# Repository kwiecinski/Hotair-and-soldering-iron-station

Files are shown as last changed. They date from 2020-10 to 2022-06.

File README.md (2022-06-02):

# Hotair and soldering iron station
DIY station based on STM32F103C6T8 uC that uses standard WEP/Yihua hotair flask with fan and WEP/Yihua 907A 50W soldering iron + T12 soldering iron. 

# 1. TOOLS
- PCB made in KiCAD v6.0
- 3D model made in DesignSpark Mechanical 5.0
- STM32CubeIDE v1.5 development platform

# 2. Features

# 3. Hardware

### Main PCB schematic
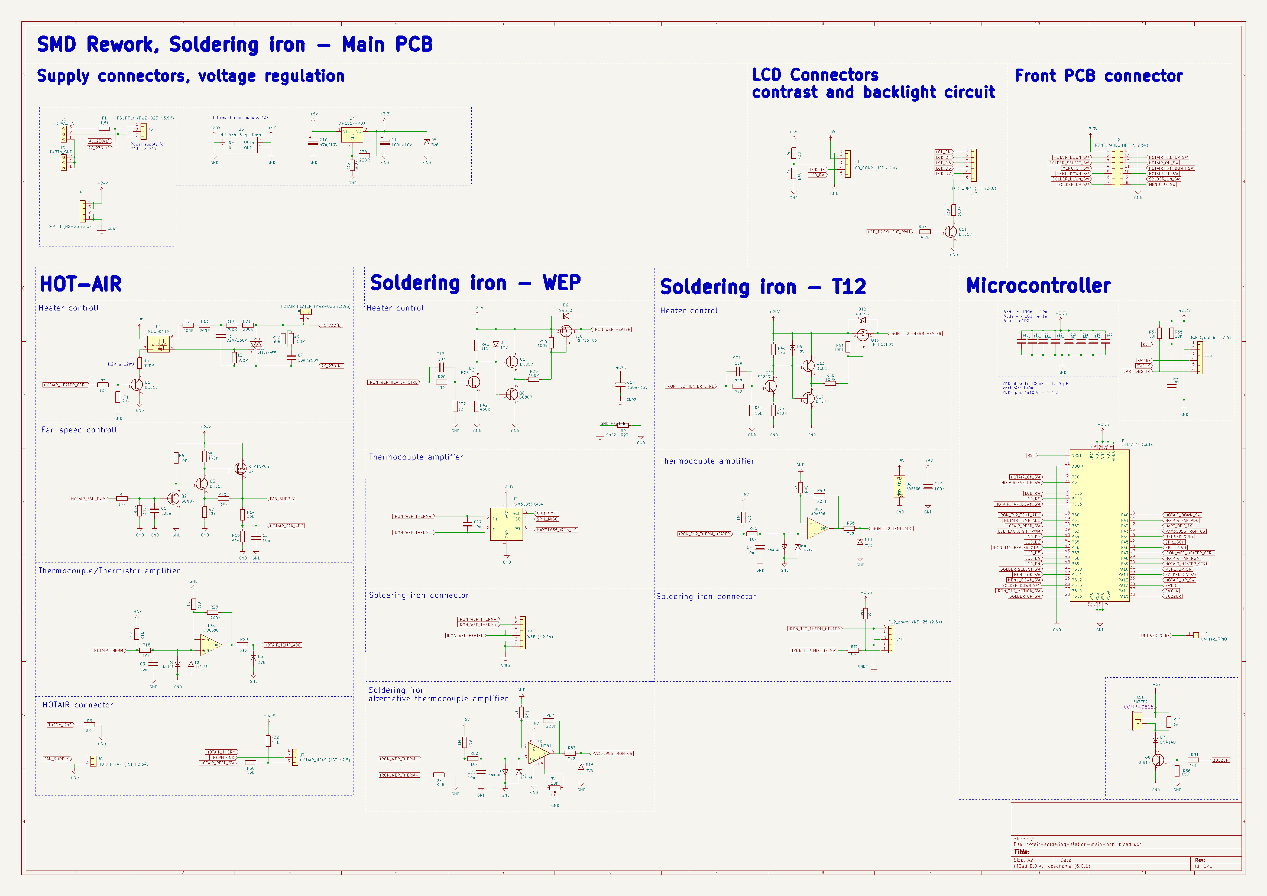
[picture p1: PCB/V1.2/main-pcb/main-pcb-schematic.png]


### Front PCB schematic
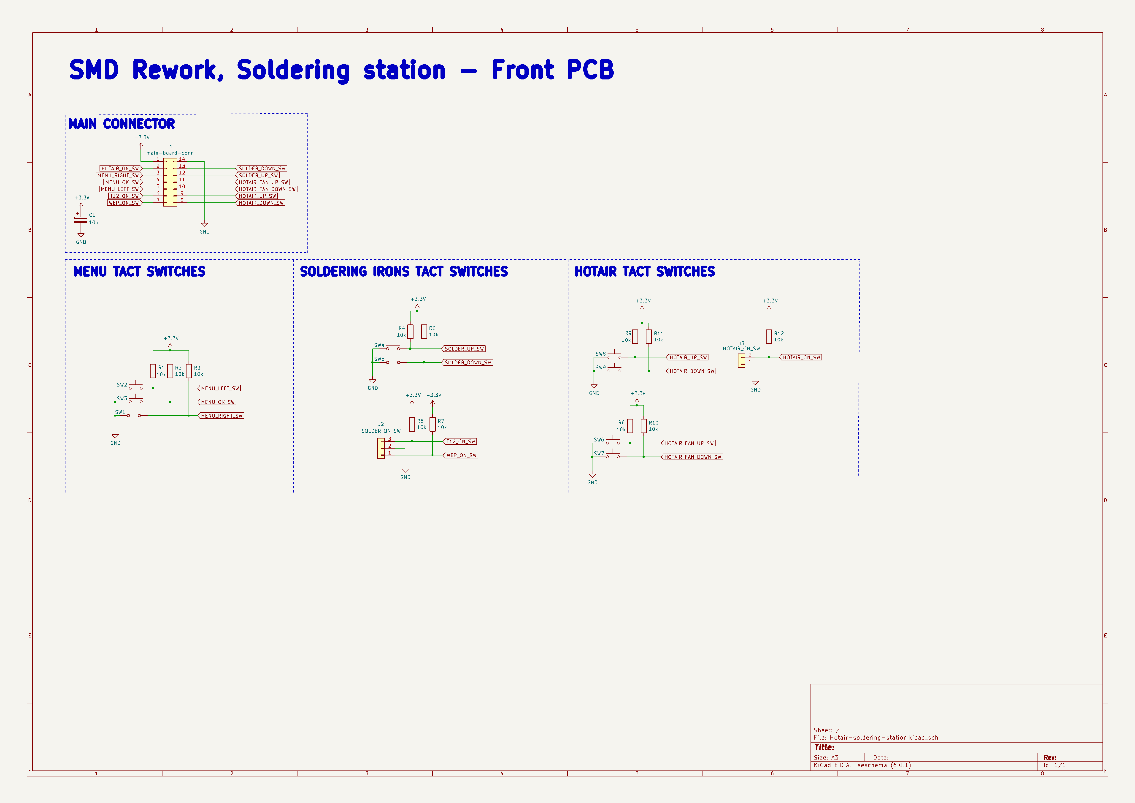
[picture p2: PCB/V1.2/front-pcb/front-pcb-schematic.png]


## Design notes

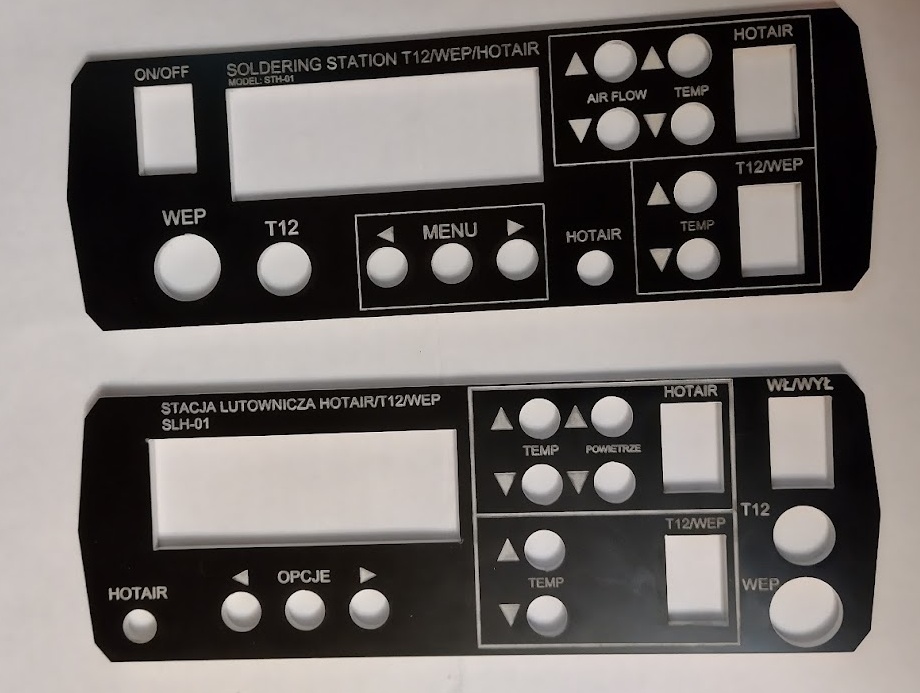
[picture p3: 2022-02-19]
docs/photos/front_panel_1.jpg

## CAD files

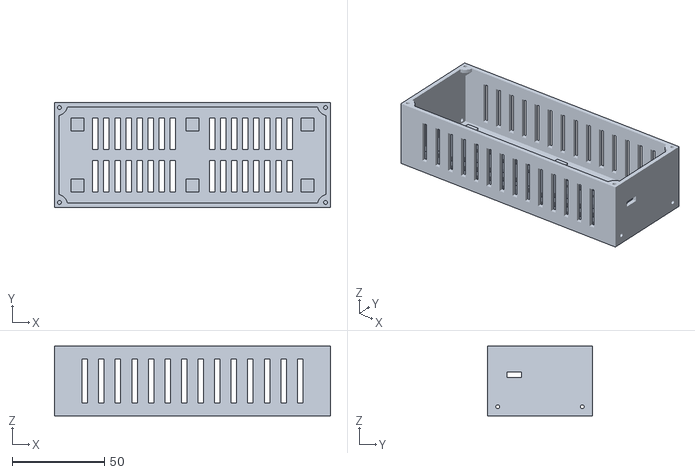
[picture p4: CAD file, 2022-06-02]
case/3D Print Models/STL/SMPS case - obudowa główna.stl
150.0 x 57.0 x 38.0

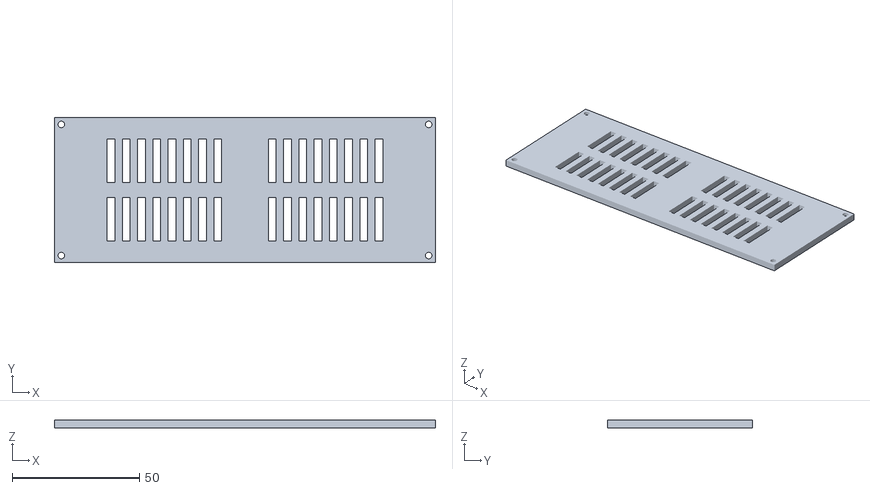
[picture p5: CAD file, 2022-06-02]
case/3D Print Models/STL/SMPS case - pokrywka.stl
150.0 x 57.0 x 3.00

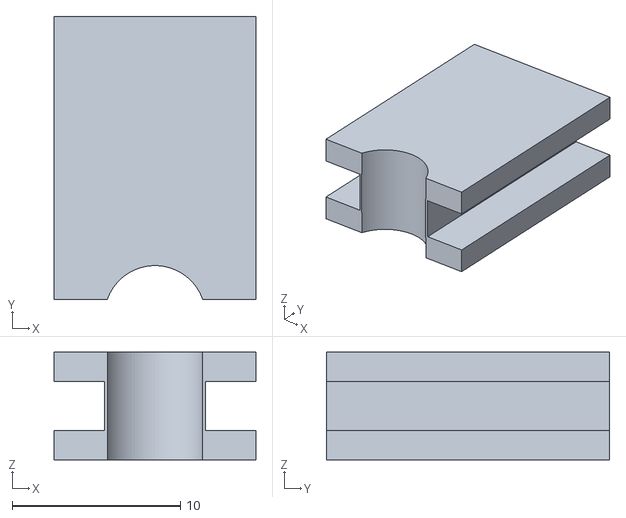
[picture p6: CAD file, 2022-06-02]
case/3D Print Models/STL/cable latch.stl
12.0 x 16.8 x 6.40

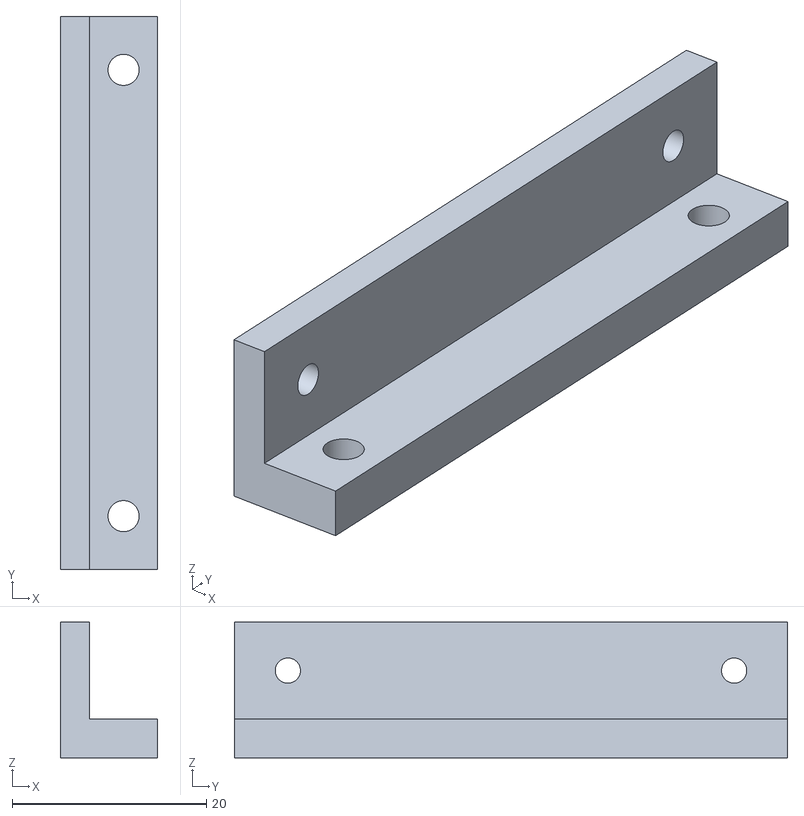
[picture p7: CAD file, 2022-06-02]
case/3D Print Models/STL/SMPS case - stopa.stl
10.0 x 57.0 x 14.0

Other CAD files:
case/Z1_Complete_documentation/Z1_2013.dwg

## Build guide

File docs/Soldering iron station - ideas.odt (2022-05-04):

1. Schematy
a. Lutownica WEP 907F

Wyjście mocy na grzałkę – stan niski brak napięcia na grzałce

Częstotliwość kluczowania >20kHz – względy akustyczne słychać kluczowanie w grzałce

Nie schodzić z wypełnieniem impulsu <10% - brak sterowania np. pushpull, nie zdąży przeładować bramki przy tej częstotliwości

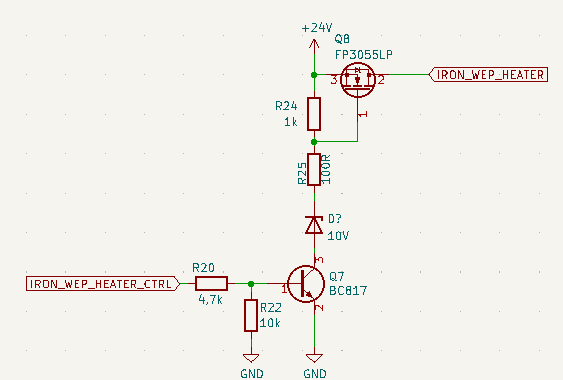
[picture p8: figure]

Pomiar temperatury:

Termopara w lutownicy – typ K – czułość 41uV/C.

Pomiar zawsze gdy grzałka nie jest zasilana! (zakłócenia)

MAX31855 nie współpracuje z grzałkami na masie, tylko izolowane !

Wykrywa rozwarcie, zwarcie itd.

Automatyczna kompensacja refrence junction.

TIM3 CH2 – konflikt z SPI1

Rozwiązania:

- Wyłączać SPI na czas działania PWM TIM3

- PA7 jako GPIO i sterować ręcznie a TIM3 przeznaczyć na timer sprzętowy ogólnego przeznaczenia

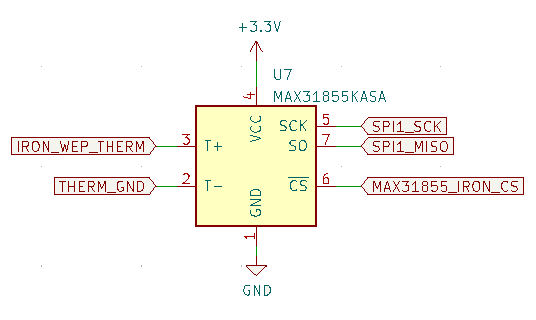
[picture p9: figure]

a. Lutownica T12

Grot zintegrowany z grzałką. Tylko trzy wyprowadzenia zasilanie i ziemia.

Grzałka jest w szeregu z termoelementem, niezbędne specjalne podejście do pomiaru.

Pomiar zawsze gdy grzałka nie jest zasilana! (inaczej nie da się)

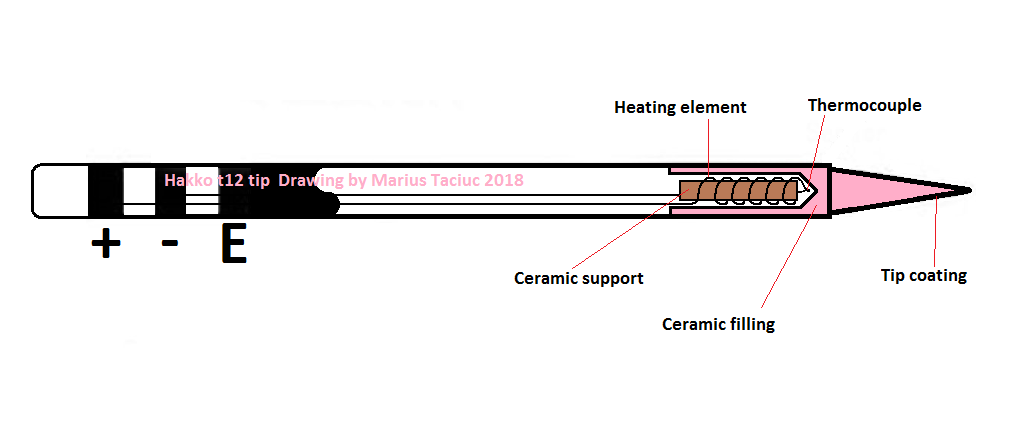
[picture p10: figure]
Hakko t12 thermocouple is not Type K! | Details | Hackaday.io

Wyjście mocy na grzałke – zasady te same co w WEP.

Wzmocnienie G=201

Termopara nie typu K, stop nieznany czułość 21uV/C

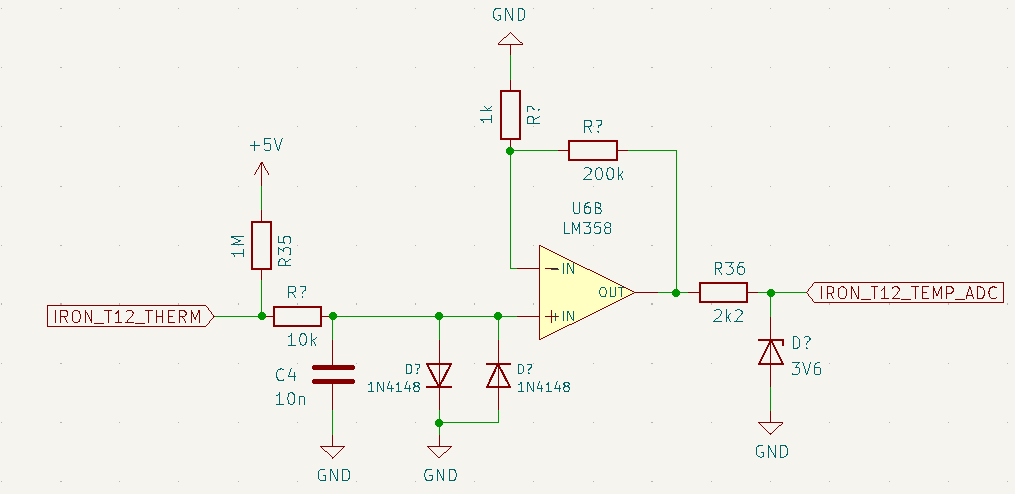
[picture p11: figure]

c) HOTAIR

Optotriak z automatycznym przejściem przez zero – sterowanie długością włączenia minimum pół okresu 50Hz czyli >10ms

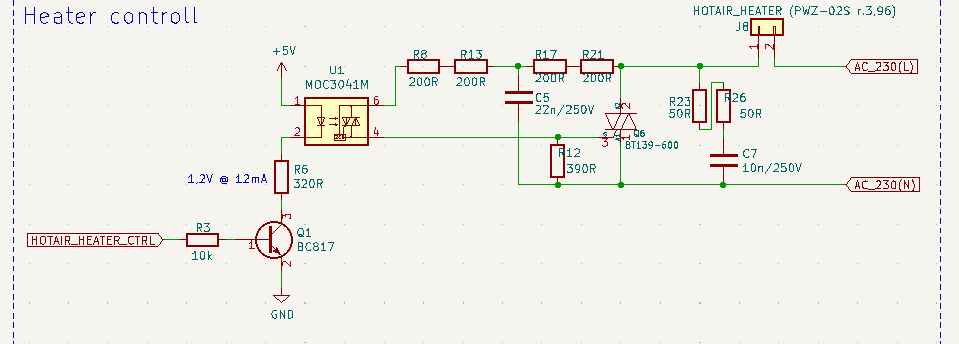
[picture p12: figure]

Pomiar temperatury:

Usunięty MAX31855.

Powody:

1. Wzmacniacz i tak musi być do pomiaru T12 – nie da rady na max bo grzałka zawsze do masy
2. Nie trzeba przerabiać kolby – w oryginalnej wspólna masa termopary z kontaktronem
3. Mamy dual omap więc szkoda żeby się jeden marnował

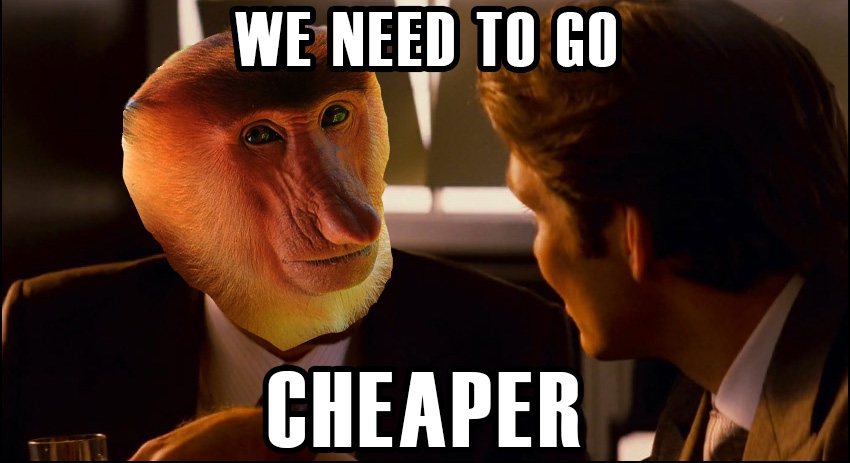
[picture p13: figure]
polak #nosaczsundajski #humorobrazkowy #heheszki - pacyfikator - Wykop.pl

Czułość 41uV/C – termopara typ K.

Schemat ten sam co w T12 z tym że wzmocnienie G=123

Pomiar zawsze gdy grzałka nie jest zasilana!

Wentylator – PWM minimum 2kHz max 10kHz

Możliwość pomiaru napięcia wentylatora

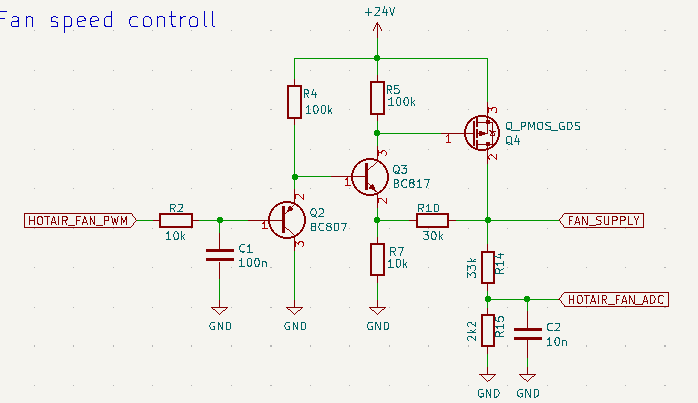
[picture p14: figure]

d) Buzzer

Rezonans przy częstotliwości 2,7kHz.

Uwaga: nie zostawiamy napięcia stałego na buzerze! Gdy nie działa zawsze na pinie stan niski!

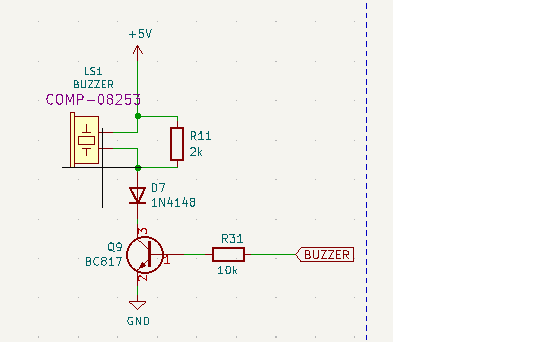
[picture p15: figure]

e) LCD

Bibloteka nie obługuje RW (jest na masie) ale jest podłączony do pinu.

PWM do regulacji podświetlenia – częstotliwość ta sama co dla buzzera bo na jednym timerze. Regulować tylko wypełeniem impulsu.

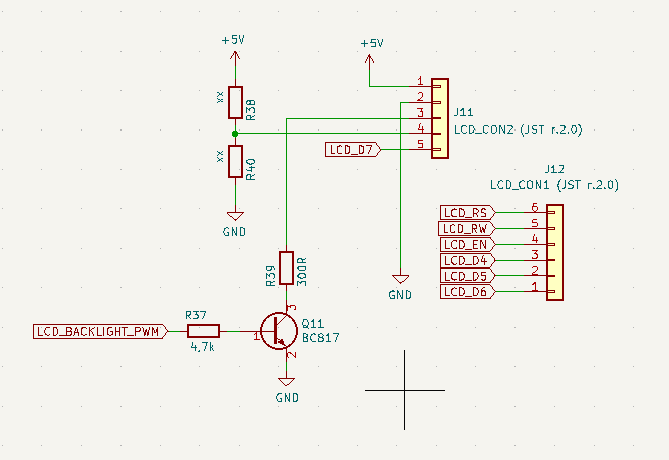
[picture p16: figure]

1. Funkcjonalność

Podstawowe:

- Ustawianie temperatury dla HOTAIR/lutownicy oraz prędkości wentylatora (nie można zejść z prędkością <40% bo się stopi hotair lub wentylator nie ruszy)

Min temp 100st max temp 450st

- Po osiągnięciu zadanej temperatury piknięcie buzzerem

- Ustawienie skoku temperatury czy wentylatora np. co 5st 10st itd.

- Standby – czas po którym po odłożeniu T12 lutownica zmniejsza temperaturę (można ustawc czas i temperaturę oraz wł/wył)

- Sleep – czas po którym po odłożeniu lutownica cała się usypia i wyłącza

- Backlight intensity – ustawienie jasności podświetlnia

- HW and SW info – werjsa oprogramowania i HW

- Buzzer on/off

- Kalibracja termopary (dla wszystkich: WEP/T12/HOTAIR)

- 3ptk dla temp. 250, 350, 430st

- powróć do domyślnych

- Wybór grotu (dla wep i T12)

- HOTAIR kontaktron, po włączeniu sprawdzamy czy jest zwarty kontaktron. Jeśli nie to trzeba odłożyć kolbę i podnieść dopiero wtedy się włącza. Po odłożeniu wentylator dalej chodzi do wychłodzenia temp. 100st

- Miganie elementu na wyświetlaczu w rytm działającego PWM

- Awarie

- Przerwanie termopary (wtedy max value na adc)

- Zwarcie do masy termopary (jeśli złączamy tranzystor a temp. Nie idzie wzrasta – błąd)

- Uszkodzenie wentylatora (ustawiony PWM a brak napięcia na adc, nie włączamy grzałki)

- Uszkodzenie tranzystora kluczującego (zwarcie – temp. Przekracza zadaną, rozwarcie – temp. Nie osiąga zadanej po określonym czasie może być zwarcie do masy termopary również)

Dodatkowe

- Praca dwóch lutownic na raz. Pomocne gdy korzystamy z różnych grotów nie trzeba przekładać.

- Uśpienie WEP – na podstawie zmian temperatury określić czy jest używana czy nie.

- Odczyt temp. uC wyświetlenie wraz z temperaturą z MAX, możliwość kompensacji refrence junction ręcznie.

- Presety temperaturowe z możliwością ustawienia

Napotkane problemy:

Resetowanie połączenia po zaprogramowaniu:

Code configurator -> SYS -> Debug -> Serial Wire

Niedziałający uart debugowy

Code configurator nie zezwala na ustawienie wyjścia jako push-pull trzeba dać rezystor.

Right-click on the syscalls.c file and select Properties. Under C/C++ Build > Settings, check Exclude resource from build.

https://shawnhymel.com/1873/how-to-use-printf-on-stm32/

Uwaga: wyłączyć prinft dla formatowania floatów.

MAX czasem daje z dupy error sprawdzać kilka razy

Ciekawostki:

Indukcyjny charakter grzałki

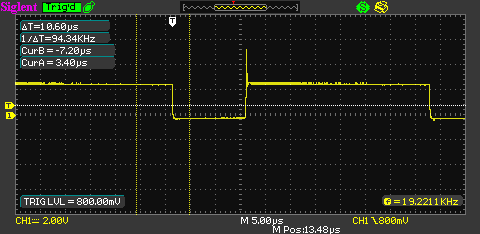
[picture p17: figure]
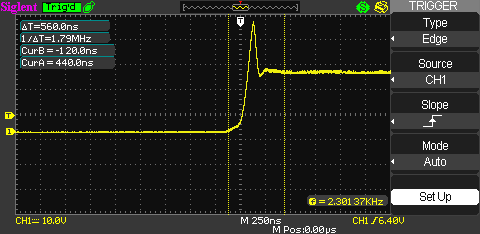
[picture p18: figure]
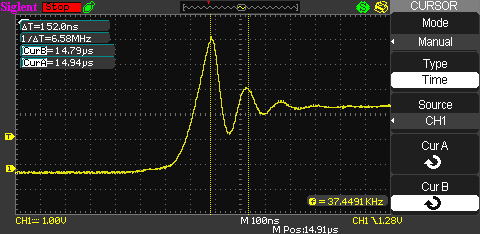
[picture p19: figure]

Triak wł/wył

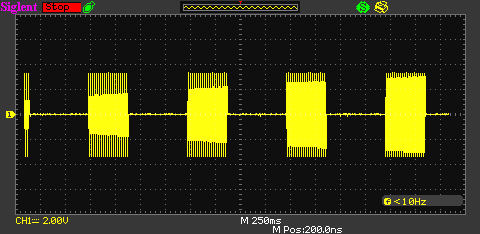
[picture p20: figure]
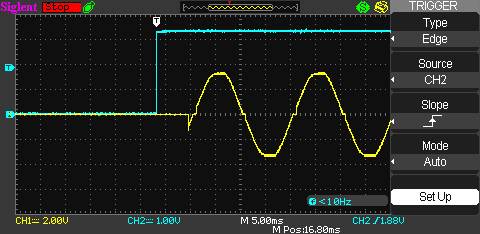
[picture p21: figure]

Analizator stanów – MAX31855

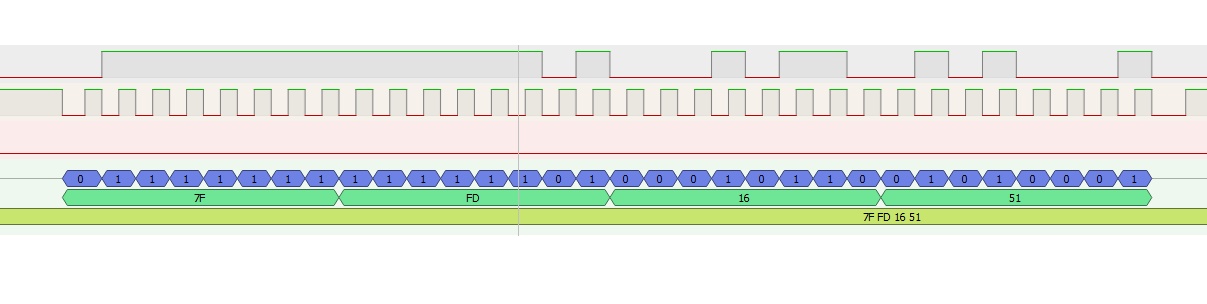
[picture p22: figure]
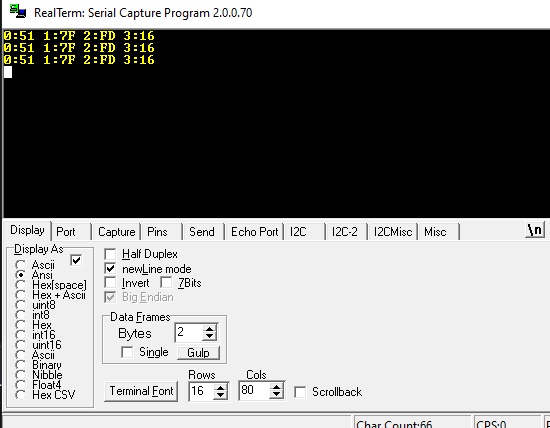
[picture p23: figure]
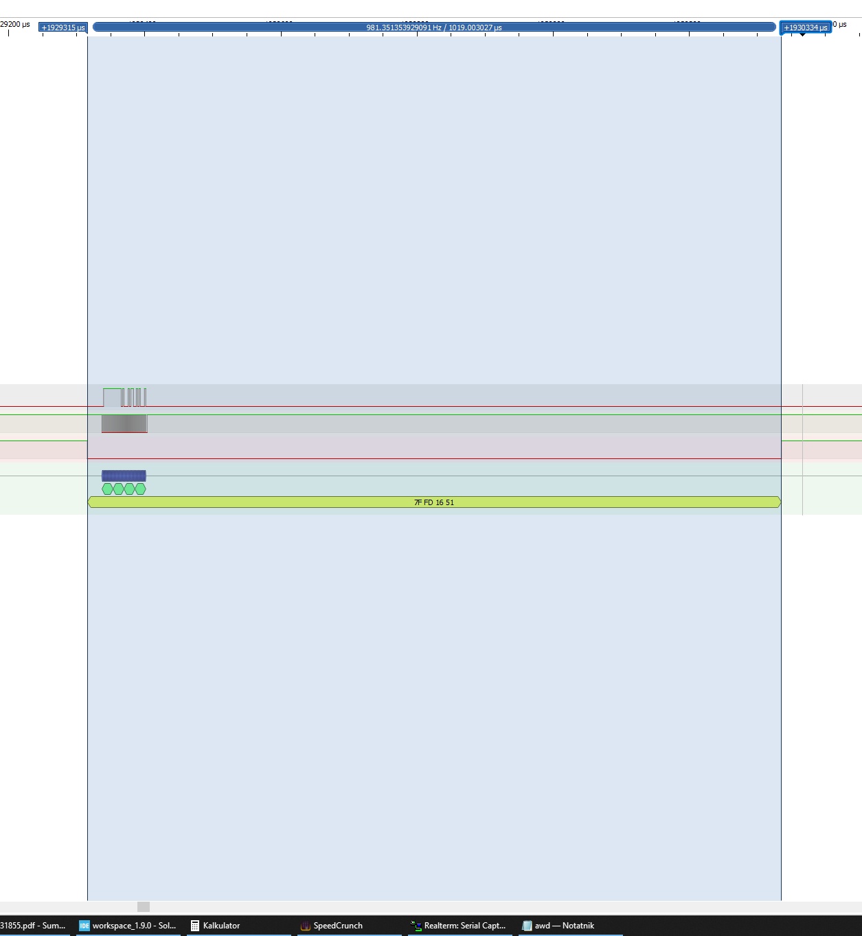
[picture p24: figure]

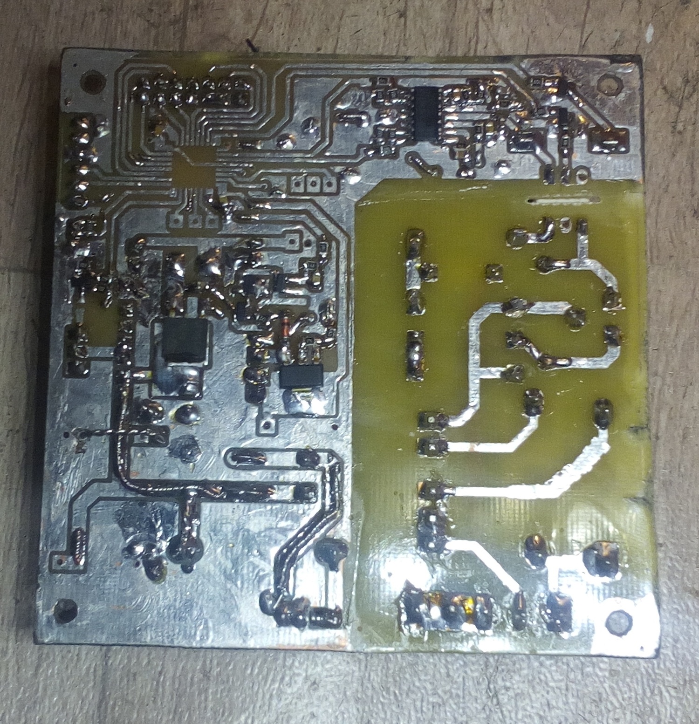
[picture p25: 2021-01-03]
docs/photos/PCB-matufacture/PCB_soldered_bottom.jpg

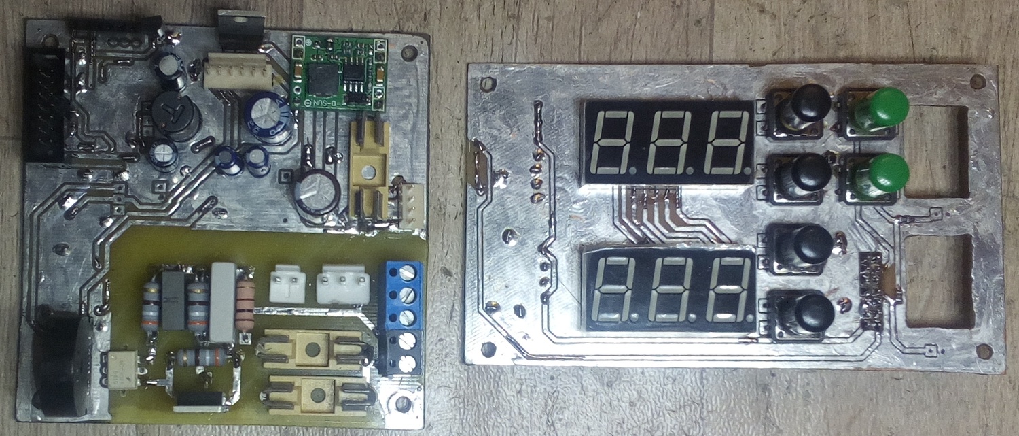
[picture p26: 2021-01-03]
docs/photos/PCB-matufacture/PCB_soldered_top.jpg

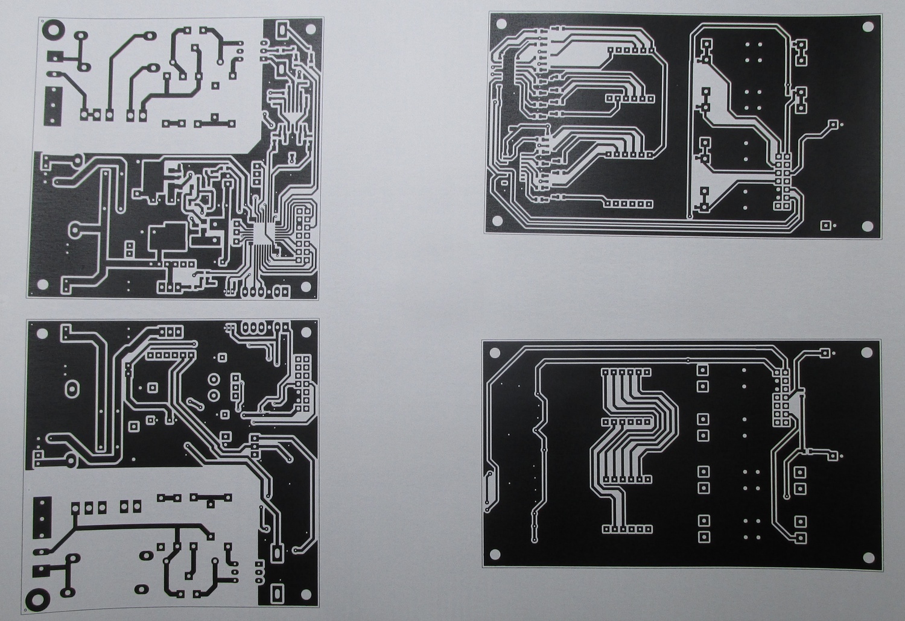
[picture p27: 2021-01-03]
docs/photos/PCB-matufacture/termotransfer_printed.JPG

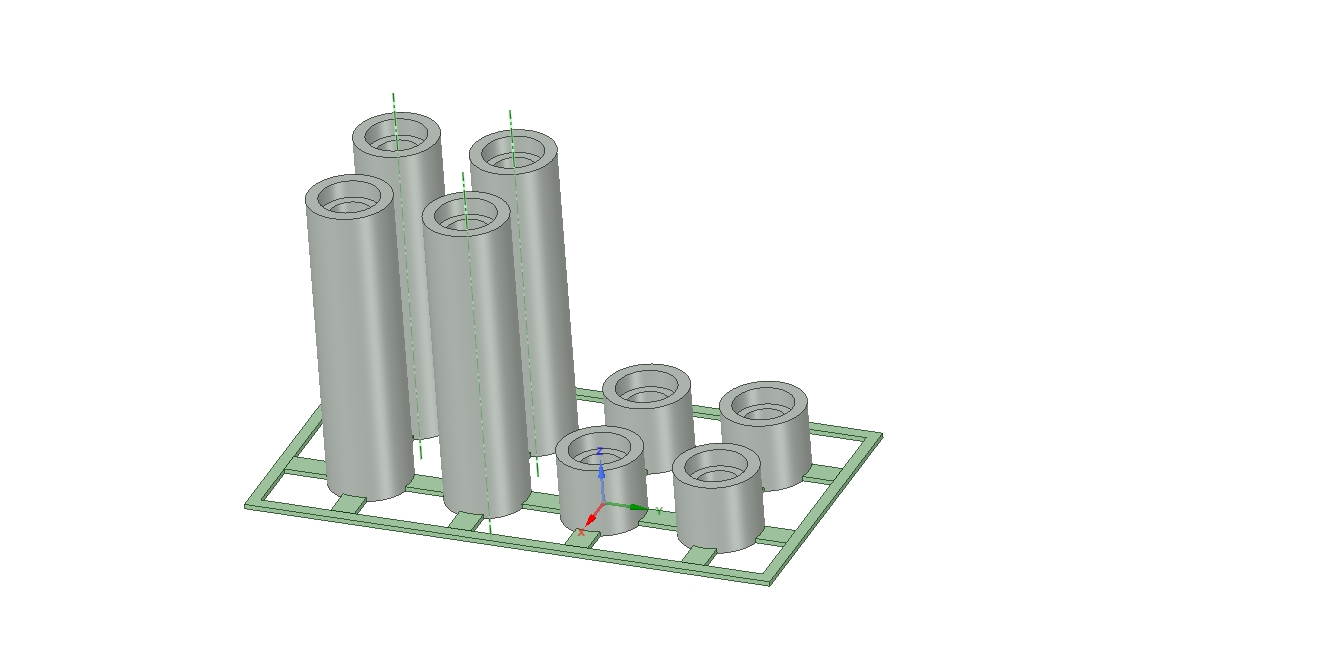
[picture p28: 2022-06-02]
case/3D Print Models/JPG/distances.jpg

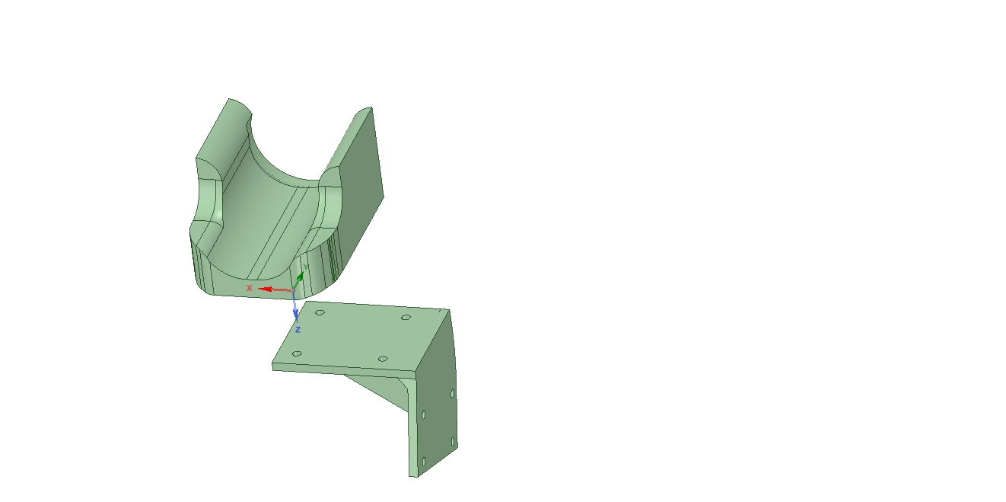
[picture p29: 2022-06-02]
case/3D Print Models/JPG/hotair holder.jpg

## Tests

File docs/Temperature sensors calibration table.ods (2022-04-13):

Zadana | Zmierzona
100 | 75
200 | 140
300 | 215
400 | 280

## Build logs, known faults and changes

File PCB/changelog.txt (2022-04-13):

V1.1
- 3V3 regulator feedback resistors values fixed
- Replace switchmode FAN converter to linear PWM
- Add MAX31855 Thermocouple interface
- Remove DC18B20
- Change MCU to STM32F103C6T6
- Change T12 6pin connector to two connector (5pin and 3pin)
- Add menu buttons
- Change display to LCD 2x16
- Add two soldering irons interface - WEP and T12 
- Change resistors in 230V heater controll circuit to smaller size
- Fix fan controll MOSFET wrong orientation

V1.2 TODO
- Add 10n capacitor and 4k7 resistor on reset
- Add 4k7 pullup resistor on debug uart
- Chane Fan regulator resistors: R7 - 2.2k, R10 - 15k, R14 - 33k, R15 - 2k2.
- Protection resistors for motion sw, reed sw

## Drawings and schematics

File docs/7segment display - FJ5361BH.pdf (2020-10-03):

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

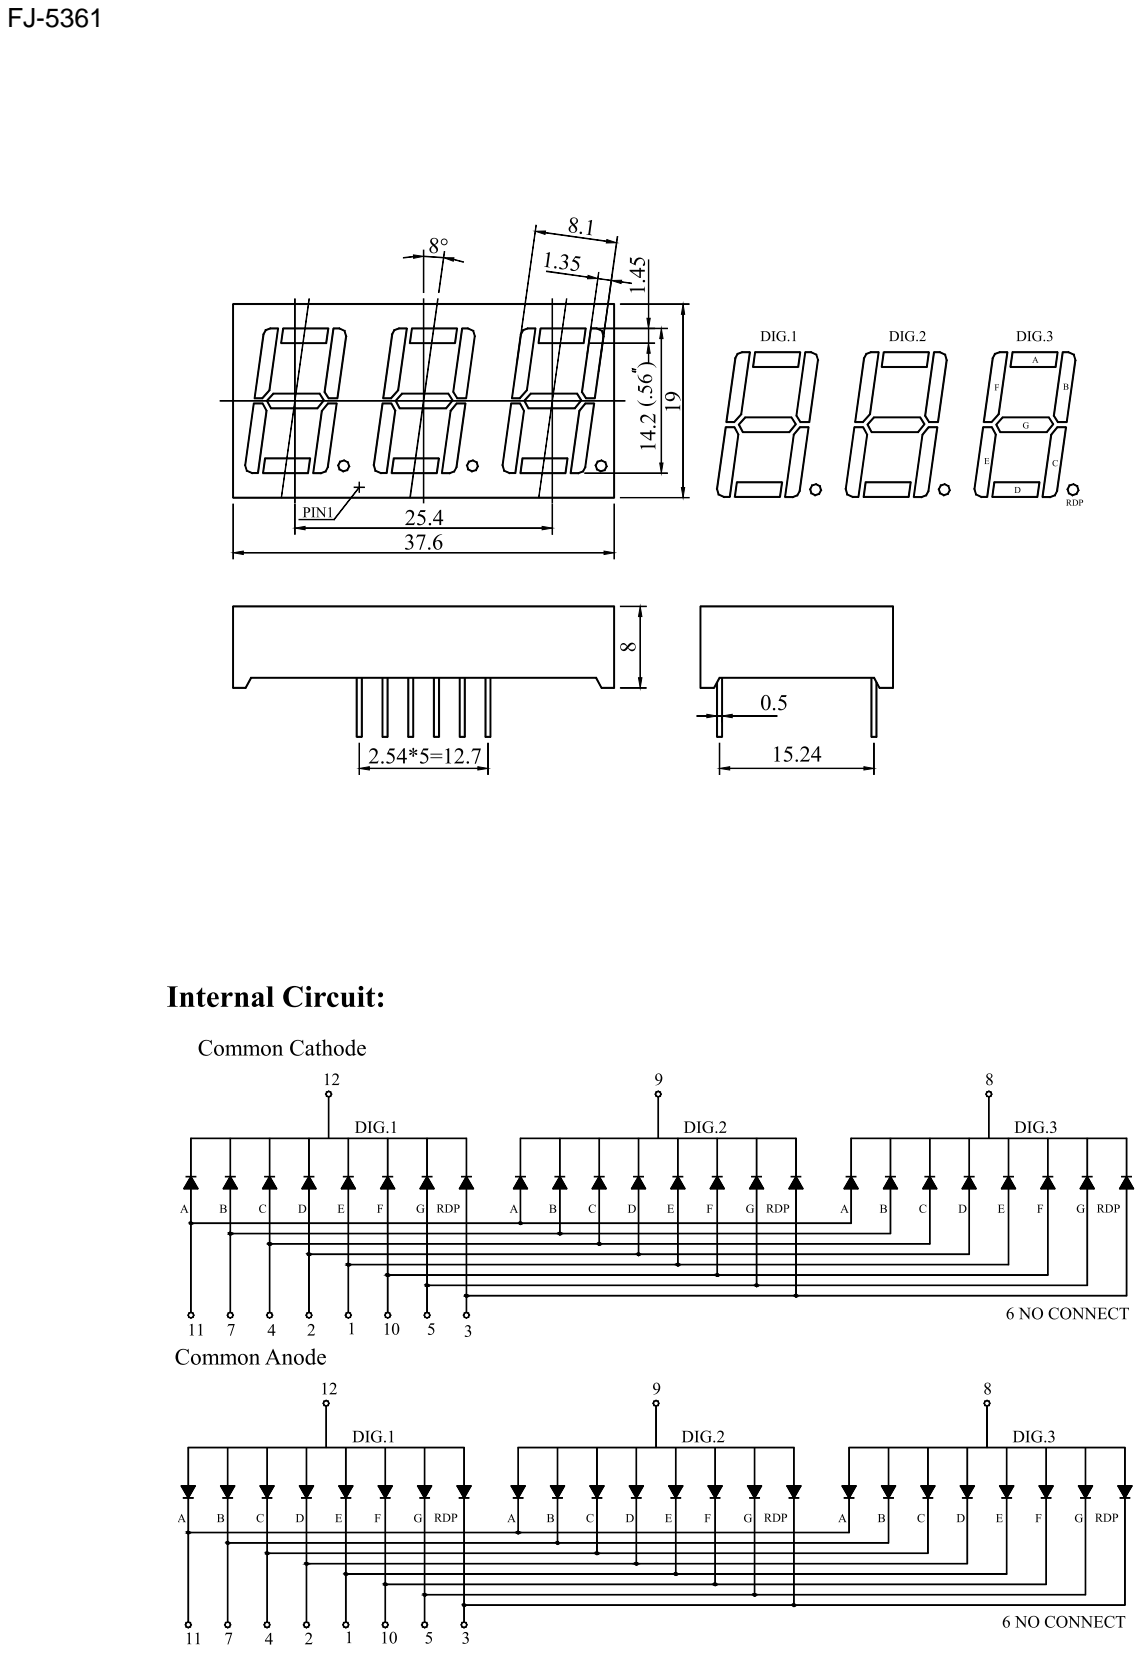
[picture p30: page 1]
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

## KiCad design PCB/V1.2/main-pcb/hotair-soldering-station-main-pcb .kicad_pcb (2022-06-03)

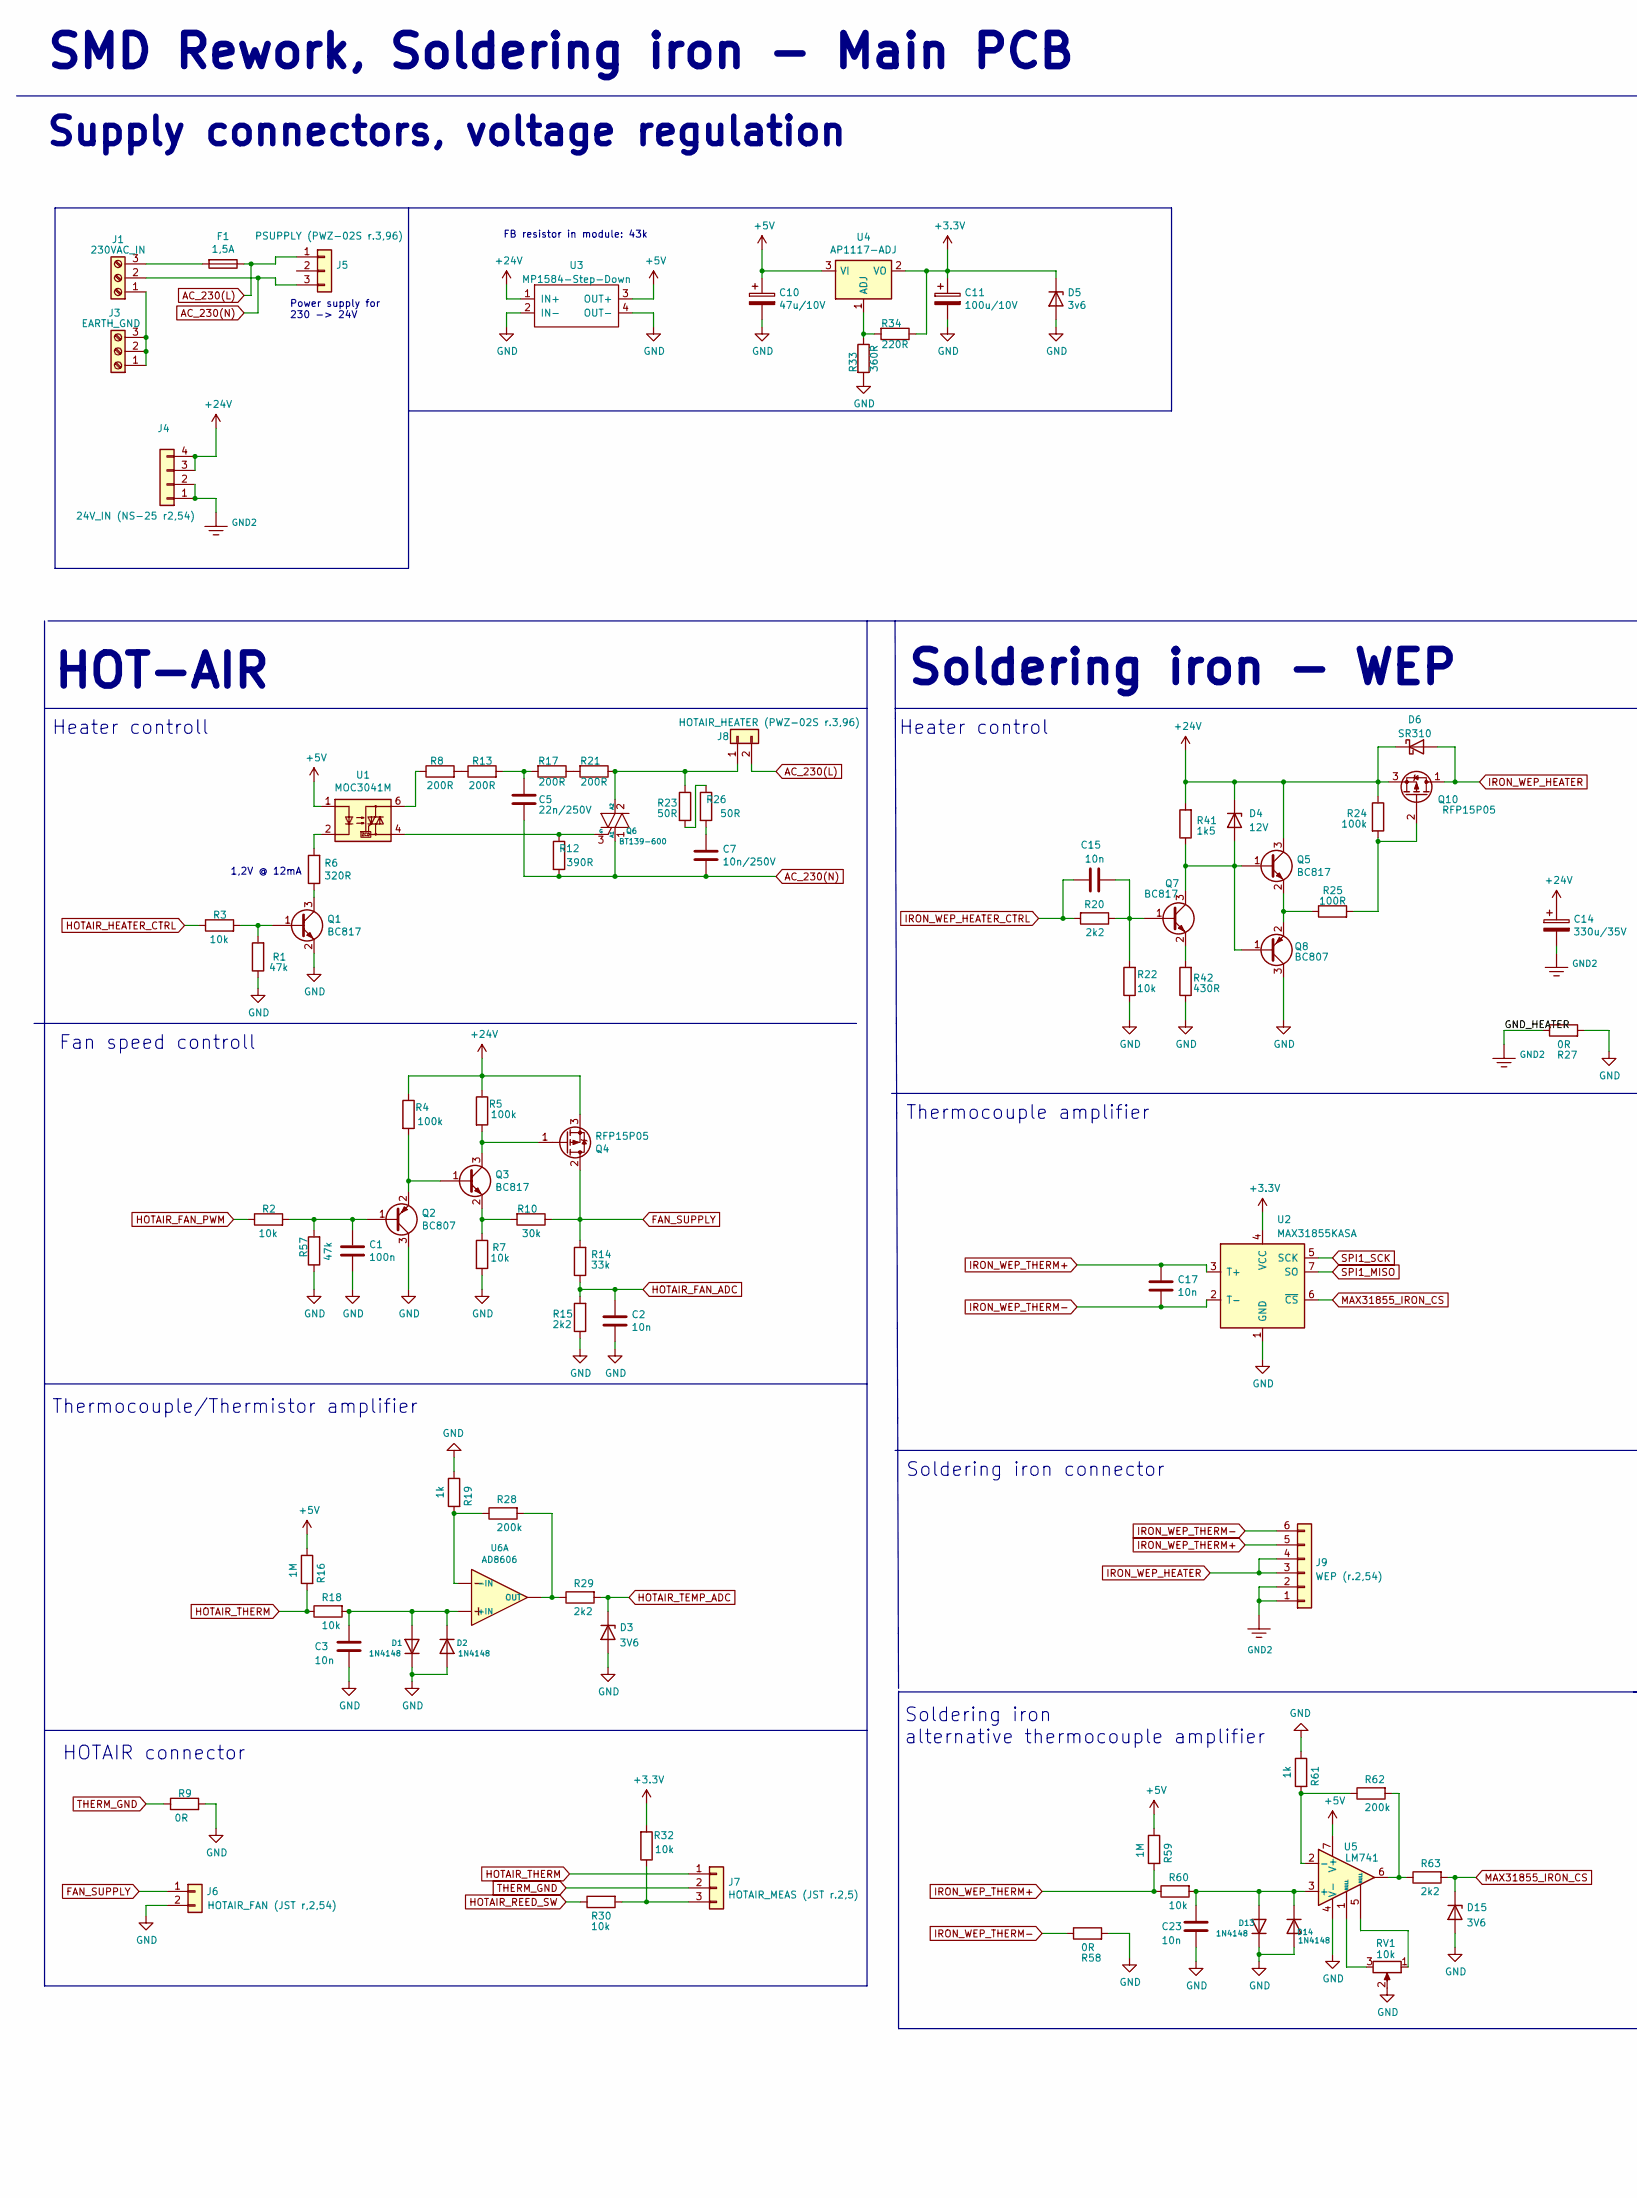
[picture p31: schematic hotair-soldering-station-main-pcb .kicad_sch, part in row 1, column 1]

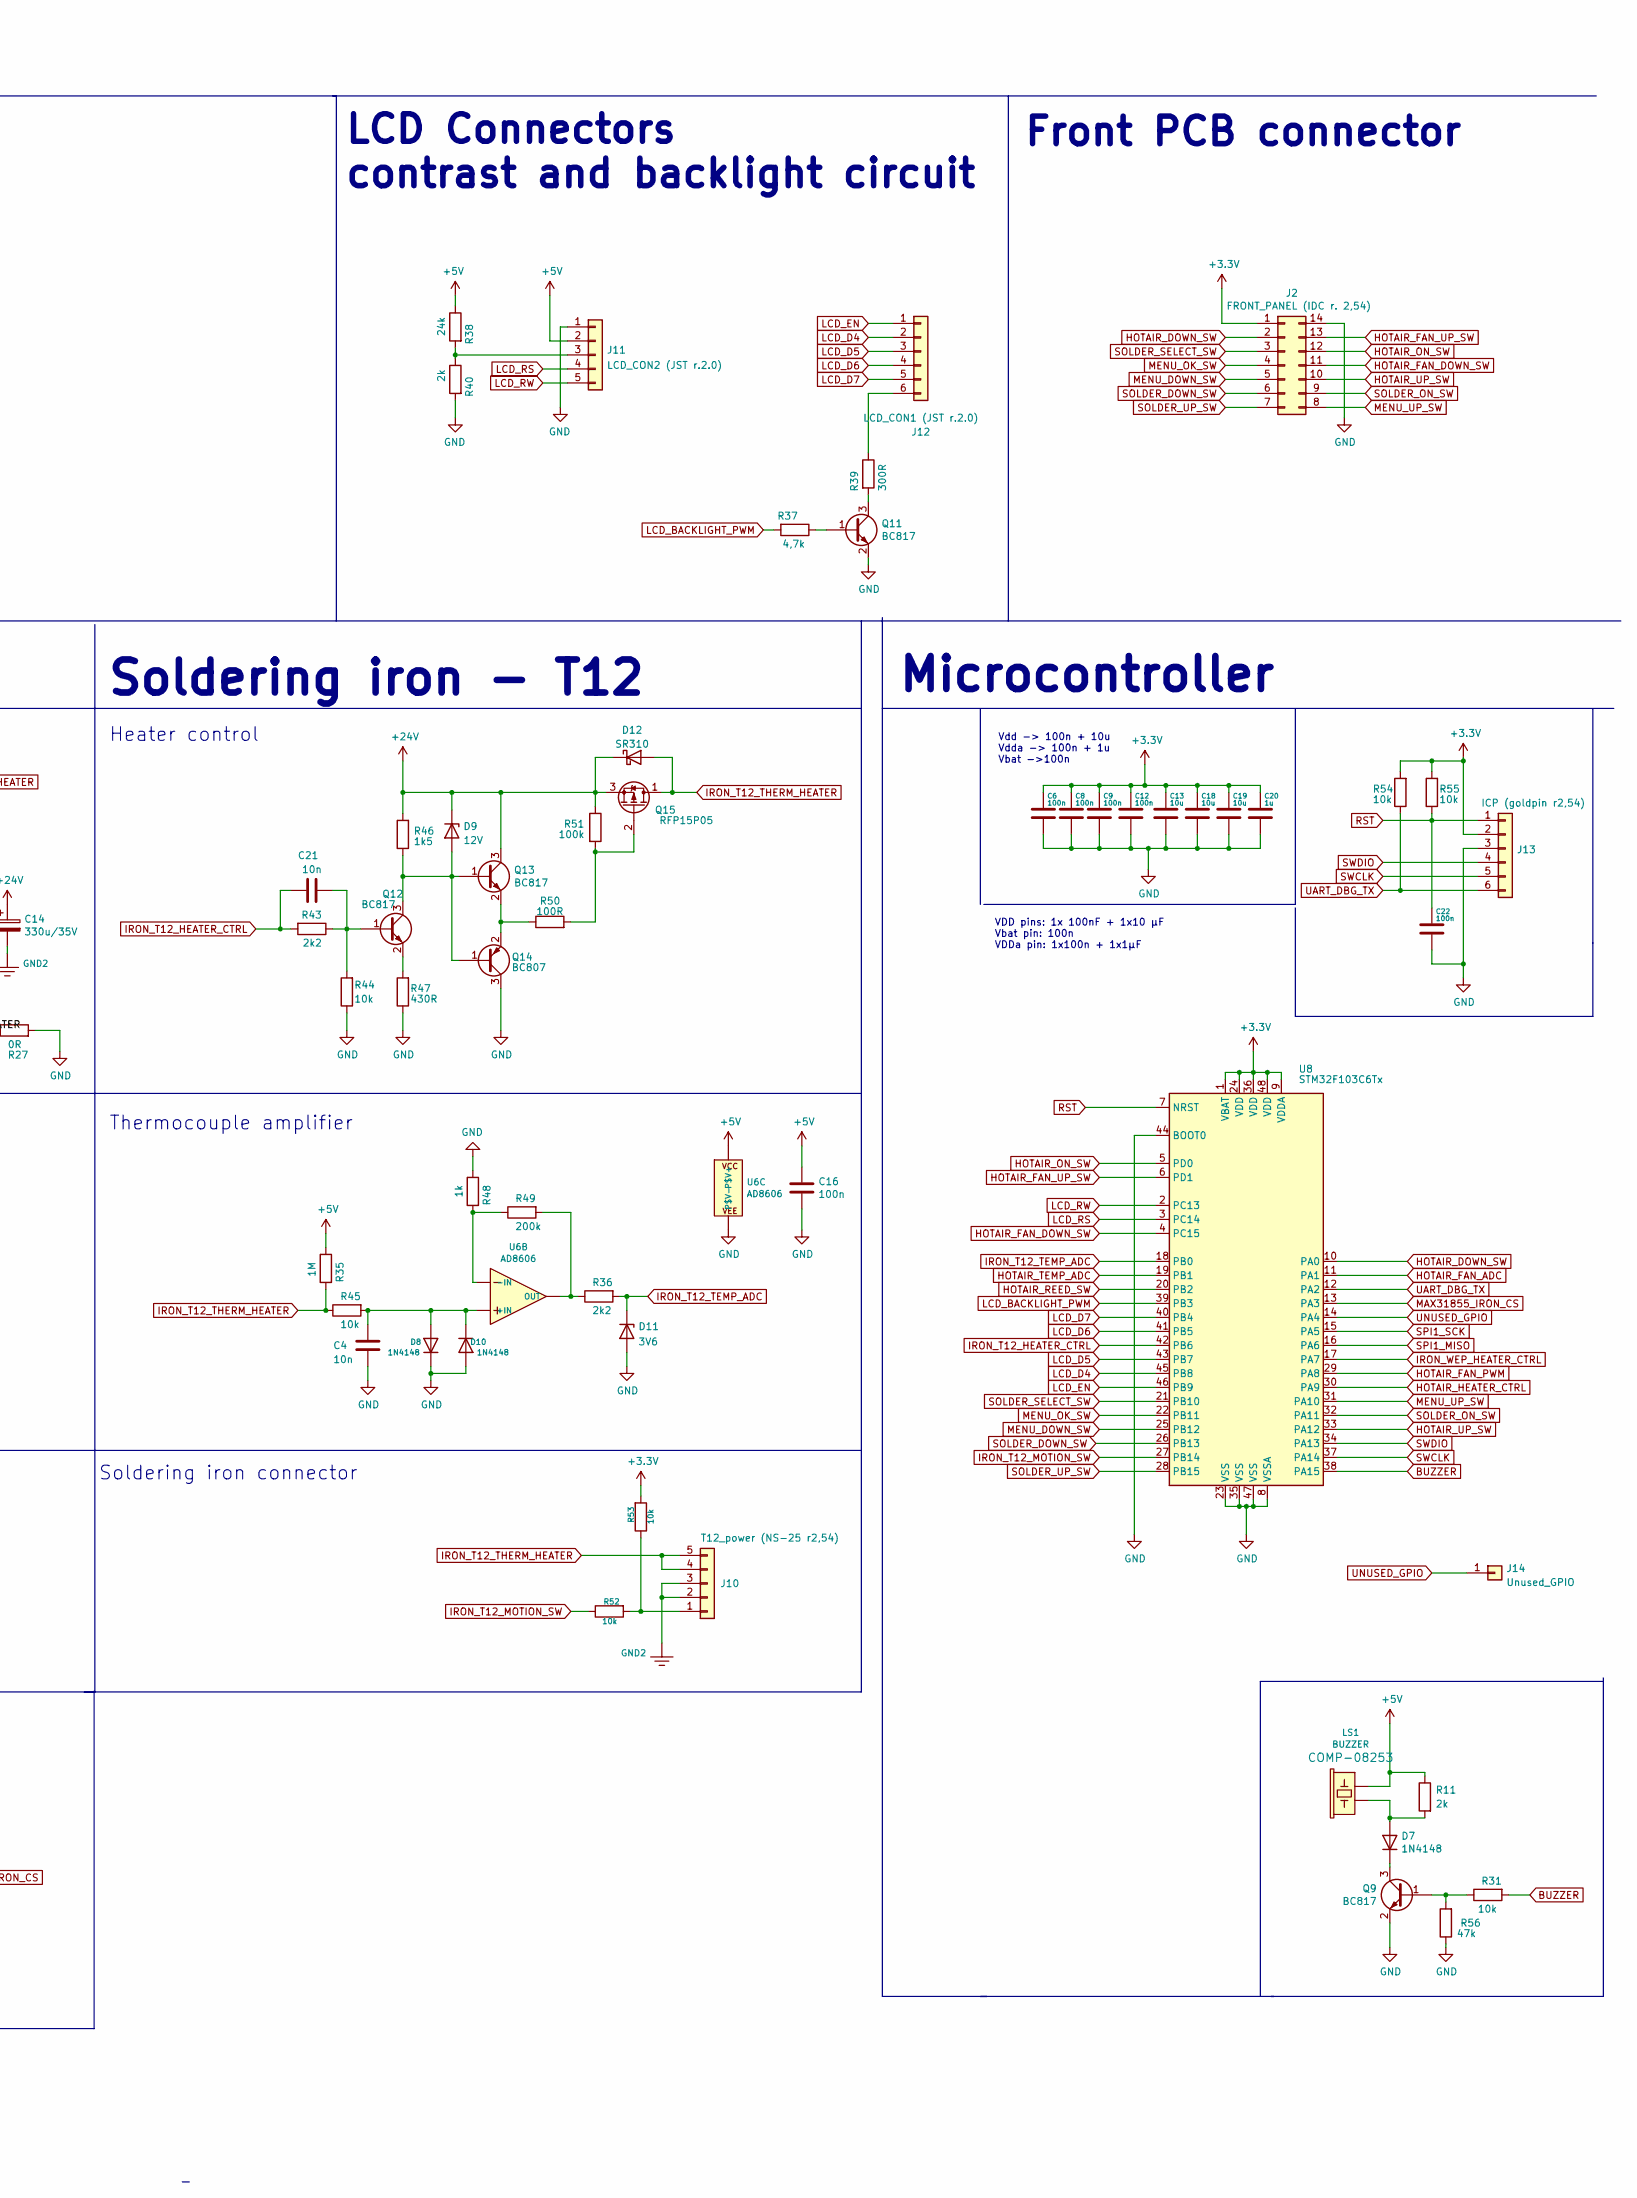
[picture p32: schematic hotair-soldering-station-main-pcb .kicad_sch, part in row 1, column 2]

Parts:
C1, C6, C8, C9, C12, C16: 100n; 0805
C2, C3, C4, C15, C17, C21, C23: 10n; 0805
C5: 22n/250V; C_Rect_L13.0mm_W5.0mm_P10.00mm_FKS3_FKP3_MKS4
C7: 10n/250V; C_Rect_L18.0mm_W5.0mm_P15.00mm_FKS3_FKP3
C10: 47u/10V; CP_Radial_D5.0mm_P2.00mm
C11: 100u/10V; CP_Radial_D5.0mm_P2.00mm
C13, C18, C19: 10u; 0805
C14: 330u/35V; CP_Radial_D10.0mm_P5.00mm
C20: 1u; 0805
C22: 100n; 0603
D1, D2, D7, D8, D10, D13, D14: 1N4148; D_MiniMELF
D3, D11, D15: 3V6; D_MiniMELF
D4, D9: 12V; D_MiniMELF
D5: 3v6; D_DO-41_SOD81_P10.16mm_Horizontal
D6, D12: SR310; D_SMA
F1: 1,5A; Fuseholder5x20_horiz_SemiClosed_Casing10x25mm
J1: 230VAC_IN; Screw-Terminal-5.00mm-3pin
J2: FRONT_PANEL (IDC r. 2,54); Conn-01x14-IDC
J3: EARTH_GND; Screw-Terminal-5.00mm-3pin
J4: 24V_IN (NS-25 r2,54); Conn-01x04-N25-W4P
J5: PSUPPLY (PWZ-02S r.3,96); Hirose_DF63-3P-3.96DSA_03x3.96mm_Straight
J6: HOTAIR_FAN (JST r,2,54); JST_XH_B02B-XH-A_02x2.50mm_Straight
J7: HOTAIR_MEAS (JST r.2,5); JST_XH_B03B-XH-A_03x2.50mm_Straight
J8: HOTAIR_HEATER (PWZ-02S r.3,96); Hirose_DF63-2P-3.96DSA_02x3.96mm_Straight
J9: WEP (r.2,54); Conn-01x06-N25-W6P
J10: T12_power (NS-25 r2,54); Conn-01x05-N25-W4P
J11: LCD_CON2 (JST r.2.0); JST_PH_B5B-PH-K_1x05_P2.00mm_Vertical
J12: LCD_CON1 (JST r.2.0); JST_PH_B6B-PH-K_1x06_P2.00mm_Vertical
J13: ICP (goldpin r2,54); Conn-01x06
J14: Unused_GPIO; SolderWirePad_single_0-8mmDrill
LS1: BUZZER; Buzzer
Q1, Q3, Q7, Q9, Q11, Q12: BC817; SOT-23
Q2, Q8, Q14: BC807; SOT-23
Q4, Q10, Q15: RFP15P05; TO-220-3_V_Thick_Pads
Q5, Q13: BC817; TSOT-23
Q6: BT139-600; TO-220-3_V_Wide_Legs
R1, R56, R57: 47k; 0805
R2, R3, R7, R18, R22, R30, R31, R32, R44, R45, R52, R53, R54, R55, R60: 10k; 0805
R4, R5, R24, R51: 100k; 0805
R6: 320R; 0805
R8, R13, R17: 200R; R_Axial_DIN0207_L6.3mm_D2.5mm_P10.16mm_Horizontal
R9, R58: 0R; 0805
R10: 30k; 0805
R11, R40: 2k; 0805
R12: 390R; R_Axial_DIN0207_L6.3mm_D2.5mm_P10.16mm_Horizontal
R14: 33k; 0805
R15, R20, R29, R36, R43, R63: 2k2; 0805
R16, R35, R59: 1M; 0805
R19, R48, R61: 1k; 0805
R21: 200R; R_Axial_DIN0207_L6.3mm_D2.5mm_P15.24mm_Horizontal
R23, R26: 50R; R_Axial_DIN0207_L6.3mm_D2.5mm_P10.16mm_Horizontal
R25, R50: 100R; 0805
R27: 0R; ShortWire
R28, R49, R62: 200k; 0805
R33: 360R; 0805
R34: 220R; 0805
R37: 4,7k; 0805
R38: 24k; 0805
R39: 300R; 0805
R41, R46: 1k5; 0805
R42, R47: 430R; 0805
RV1: 10k; Potentiometer_Bourns_3314G_Vertical
U1: MOC3041M; DIP-6_W7.62mm_LongPads
U2: MAX31855KASA; SOIC-8_3.9x4.9mm_P1.27mm
U3: MP1584-Step-Down; MP1584_Mini_3A_Step_Down_Conv
U4: AP1117-ADJ; SOT-223-3_TabPin2
U5: LM741; SO-8_3.9x4.9mm_P1.27mm
U6: AD8606; SO-8_3.9x4.9mm_P1.27mm
U8: STM32F103C6Tx; LQFP-48_7x7mm_P0.5mm

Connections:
+3V3: C6.1, C8.1, C9.1, C11.1, C12.1, C13.1, C18.1, C19.1, C20.1, D5.1 (K), J2.1, J13.2, R32.2, R34.1, R53.2, R54.2, R55.2, U2.4 (VCC), U4.2 (VO), U8.1 (VBAT), U8.9 (VDDA), U8.24 (VDD), U8.36 (VDD), U8.48 (VDD)
+5V: C10.1, C16.1, J11.2, LS1.- (2), R11.1, R16.1, R35.1, R38.1, R59.1, U1.1, U3.3 (OUT+), U4.3 (VI), U5.7 (V+), U6.8 (P$V+)
+24V: C14.1, D4.1 (K), D6.1 (K), D9.1 (K), D12.1 (K), J4.3, J4.4, Q4.3 (S), Q5.3 (C), Q10.3 (S), Q13.3 (C), Q15.3 (S), R4.1, R5.1, R24.1, R41.2, R46.2, R51.1, U3.1 (IN+)
AC_230(L): F1.1, J5.1, J8.2
AC_230(N): C5.2, C7.2, J1.2, J5.3, Q6.1 (A1), R12.2
BUZZER: R31.2, U8.38 (PA15)
FAN_SUPPLY: J6.1, Q4.2 (D), R10.1, R14.2
GND: C1.2, C2.2, C3.2, C4.2, C6.2, C8.2, C9.2, C10.2, C11.2, C12.2, C13.2, C16.2, C18.2, C19.2, C20.2, C22.2, C23.2, D1.1 (K), D2.2 (A), D3.2 (A), D5.2 (A), D8.1 (K), D10.2 (A), D11.2 (A), D13.1 (K), D14.2 (A), D15.2 (A), J2.14, J6.2, J11.1, J13.3, Q1.2 (E), Q2.3 (C), Q8.3 (C), Q9.2 (E), Q11.2 (E), Q14.3 (C), R1.1, R7.2, R9.2, R15.1, R19.1, R22.1, R27.2, R33.2, R40.2, R42.1, R44.1, R47.1, R48.1, R56.1, R57.1, R58.2, R61.1, RV1.2, U2.1 (GND), U3.2 (IN-), U3.4 (OUT-), U5.4 (V-), U6.4 (P$V-), U8.8 (VSSA), U8.23 (VSS), U8.35 (VSS), U8.44 (BOOT0), U8.47 (VSS)
GND2: C14.2, J4.1, J4.2, J9.1, J9.2, J10.2, J10.3, R27.1
HOTAIR_DOWN_SW: J2.2, U8.10 (PA0)
HOTAIR_FAN_ADC: C2.1, R14.1, R15.2, U8.11 (PA1)
HOTAIR_FAN_DOWN_SW: J2.11, U8.4 (PC15)
HOTAIR_FAN_PWM: R2.1, U8.29 (PA8)
HOTAIR_FAN_UP_SW: J2.13, U8.6 (PD1)
HOTAIR_HEATER_CTRL: R3.1, U8.30 (PA9)
HOTAIR_ON_SW: J2.12, U8.5 (PD0)
HOTAIR_REED_SW: R30.1, U8.20 (PB2)
HOTAIR_TEMP_ADC: D3.1 (K), R29.2, U8.19 (PB1)
HOTAIR_THERM: J7.1, R16.2, R18.1
HOTAIR_UP_SW: J2.10, U8.33 (PA12)
IRON_T12_HEATER_CTRL: C21.1, R43.2, U8.42 (PB6)
IRON_T12_MOTION_SW: R52.1, U8.27 (PB14)
IRON_T12_TEMP_ADC: D11.1 (K), R36.2, U8.18 (PB0)
IRON_T12_THERM_HEATER: D12.2 (A), J10.4, J10.5, Q15.1 (D), R35.2, R45.1
IRON_WEP_HEATER: D6.2 (A), J9.3, J9.4, Q10.1 (D)
IRON_WEP_HEATER_CTRL: C15.1, R20.2, U8.17 (PA7)
IRON_WEP_THERM+: C17.1, J9.5, R59.2, R60.1, U2.3 (T+)
IRON_WEP_THERM-: C17.2, J9.6, R58.1, U2.2 (T-)
LCD_BACKLIGHT_PWM: R37.2, U8.39 (PB3)
LCD_D4: J12.2, U8.45 (PB8)
LCD_D5: J12.3, U8.43 (PB7)
LCD_D6: J12.4, U8.41 (PB5)
LCD_D7: J12.5, U8.40 (PB4)
LCD_EN: J12.1, U8.46 (PB9)
LCD_RS: J11.4, U8.3 (PC14)
LCD_RW: J11.5, U8.2 (PC13)
MAX31855_IRON_CS: D15.1 (K), R63.2, U2.6 (~CS), U8.13 (PA3)
MENU_DOWN_SW: J2.5, U8.25 (PB12)
MENU_OK_SW: J2.4, U8.22 (PB11)
MENU_UP_SW: J2.8, U8.31 (PA10)
unnamed: C1.1, Q2.1 (B), R2.2, R57.2
unnamed: C3.1, D1.2 (A), D2.1 (K), R18.2, U6.3 (+IN)
unnamed: C4.1, D8.2 (A), D10.1 (K), R45.2, U6.5 (+IN)
unnamed: C5.1, R13.2, R17.2
unnamed: C7.1, R26.2
unnamed: C15.2, Q7.1 (B), R20.1, R22.2
unnamed: C21.2, Q12.1 (B), R43.1, R44.2
unnamed: C23.1, D13.2 (A), D14.1 (K), R60.2, U5.3 (+)
unnamed: D7.1 (K), Q9.3 (C)
unnamed: D7.2 (A), LS1.+ (1), R11.2
unnamed: D9.2 (A), Q12.3 (C), Q13.1 (B), Q14.1 (B), R46.1
unnamed: F1.2, J1.3
unnamed: J1.1, J3.1, J3.2, J3.3
unnamed: J7.3, R30.2, R32.1
unnamed: J8.1, Q6.2 (A2), R21.1, R23.1
unnamed: J10.1, R52.2, R53.1
unnamed: J11.3, R38.2, R40.1
unnamed: J12.6, R39.1
unnamed: Q1.1 (B), R1.2, R3.2
unnamed: Q1.3 (C), R6.1
unnamed: Q2.2 (E), Q3.1 (B), R4.2
unnamed: Q3.2 (E), R7.1, R10.2
unnamed: Q3.3 (C), Q4.1 (G), R5.2
unnamed: D4.2 (A), Q5.1 (B), Q7.3 (C), Q8.1 (B), R41.1
unnamed: Q5.2 (E), Q8.2 (E), R25.1
unnamed: Q6.3 (G), R12.1, U1.4
unnamed: Q7.2 (E), R42.2
unnamed: Q9.1 (B), R31.1, R56.2
unnamed: Q10.2 (G), R24.2, R25.2
unnamed: Q11.1 (B), R37.1
unnamed: Q11.3 (C), R39.2
unnamed: Q12.2 (E), R47.2
unnamed: Q13.2 (E), Q14.2 (E), R50.1
unnamed: Q15.2 (G), R50.2, R51.2
unnamed: R6.2, U1.2
unnamed: R8.1, U1.6
unnamed: R8.2, R13.1
unnamed: R17.1, R21.2
unnamed: R19.2, R28.1, U6.2 (-IN)
unnamed: R23.2, R26.1
unnamed: R28.2, R29.1, U6.1 (OUT)
unnamed: R33.1, R34.2, U4.1 (ADJ)
unnamed: R36.1, R49.2, U6.7 (OUT)
unnamed: R48.2, R49.1, U6.6 (-IN)
unnamed: R61.2, R62.1, U5.2 (-)
unnamed: R62.2, R63.1, U5.6
unnamed: RV1.1, U5.5 (NULL)
unnamed: RV1.3, U5.1 (NULL)
RST: C22.1, J13.1, R55.1, U8.7 (NRST)
SOLDER_DOWN_SW: J2.6, U8.26 (PB13)
SOLDER_ON_SW: J2.9, U8.32 (PA11)
SOLDER_SELECT_SW: J2.3, U8.21 (PB10)
SOLDER_UP_SW: J2.7, U8.28 (PB15)
SPI1_MISO: U2.7 (SO), U8.16 (PA6)
SPI1_SCK: U2.5 (SCK), U8.15 (PA5)
SWCLK: J13.5, U8.37 (PA14)
SWDIO: J13.4, U8.34 (PA13)
THERM_GND: J7.2, R9.1
UART_DBG_TX: J13.6, R54.1, U8.12 (PA2)
UNUSED_GPIO: J14.1, U8.14 (PA4)

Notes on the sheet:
FB resistor in module: 43k
Soldering iron connector
Heater controll
Front PCB connector
SMD Rework, Soldering iron - Main PCB
Thermocouple amplifier
Soldering iron alternative thermocouple amplifier
Supply connectors, voltage regulation
Heater control
Fan speed controll
Soldering iron - T12
Microcontroller
Thermocouple/Thermistor amplifier
HOT-AIR
LCD Connectors contrast and backlight circuit
Vdd -> 100n + 10u Vdda -> 100n + 1u Vbat ->100n
HOTAIR connector
1,2V @ 12mA
Power supply for 230 -> 24V
Soldering iron - WEP
VDD pins: 1x 100nF + 1x10 µF Vbat pin: 100n VDDa pin: 1x100n + 1x1µF

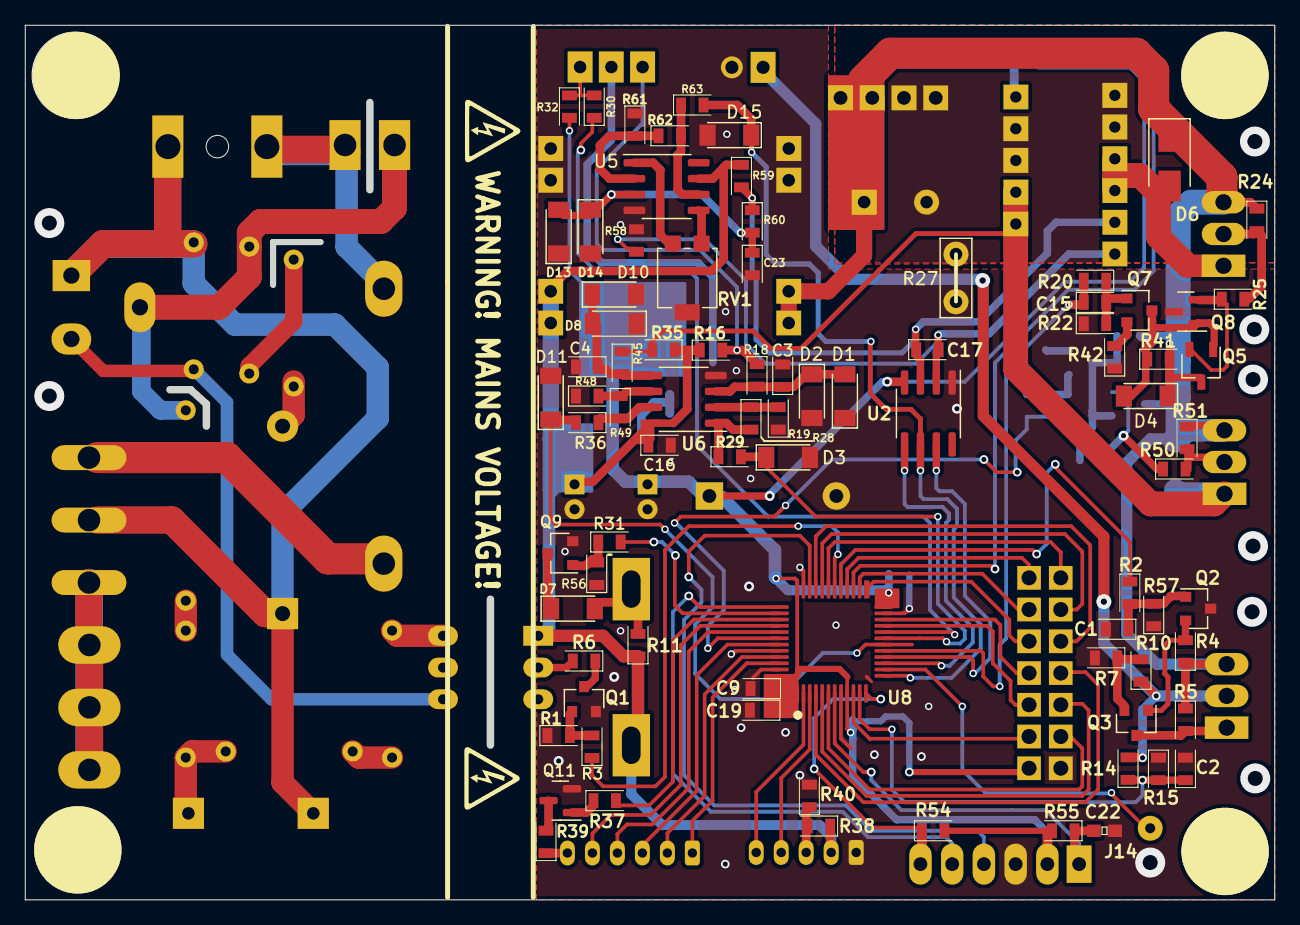
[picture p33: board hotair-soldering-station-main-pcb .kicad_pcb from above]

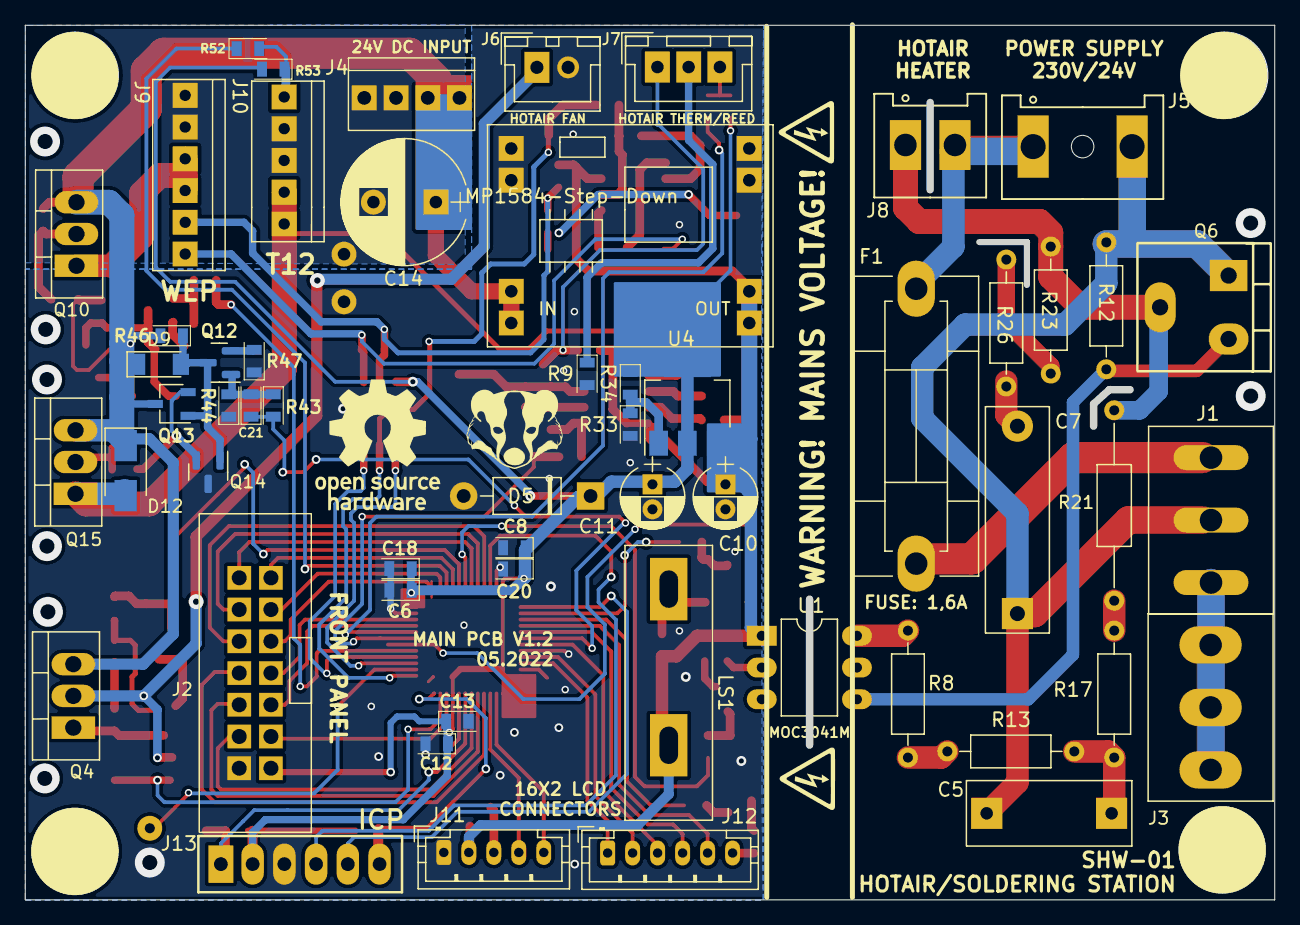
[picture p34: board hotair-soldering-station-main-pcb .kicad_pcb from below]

Board: 2 copper layers, 100.0 x 70.0 mm, 140 parts (56 on the bottom side), 100 nets.

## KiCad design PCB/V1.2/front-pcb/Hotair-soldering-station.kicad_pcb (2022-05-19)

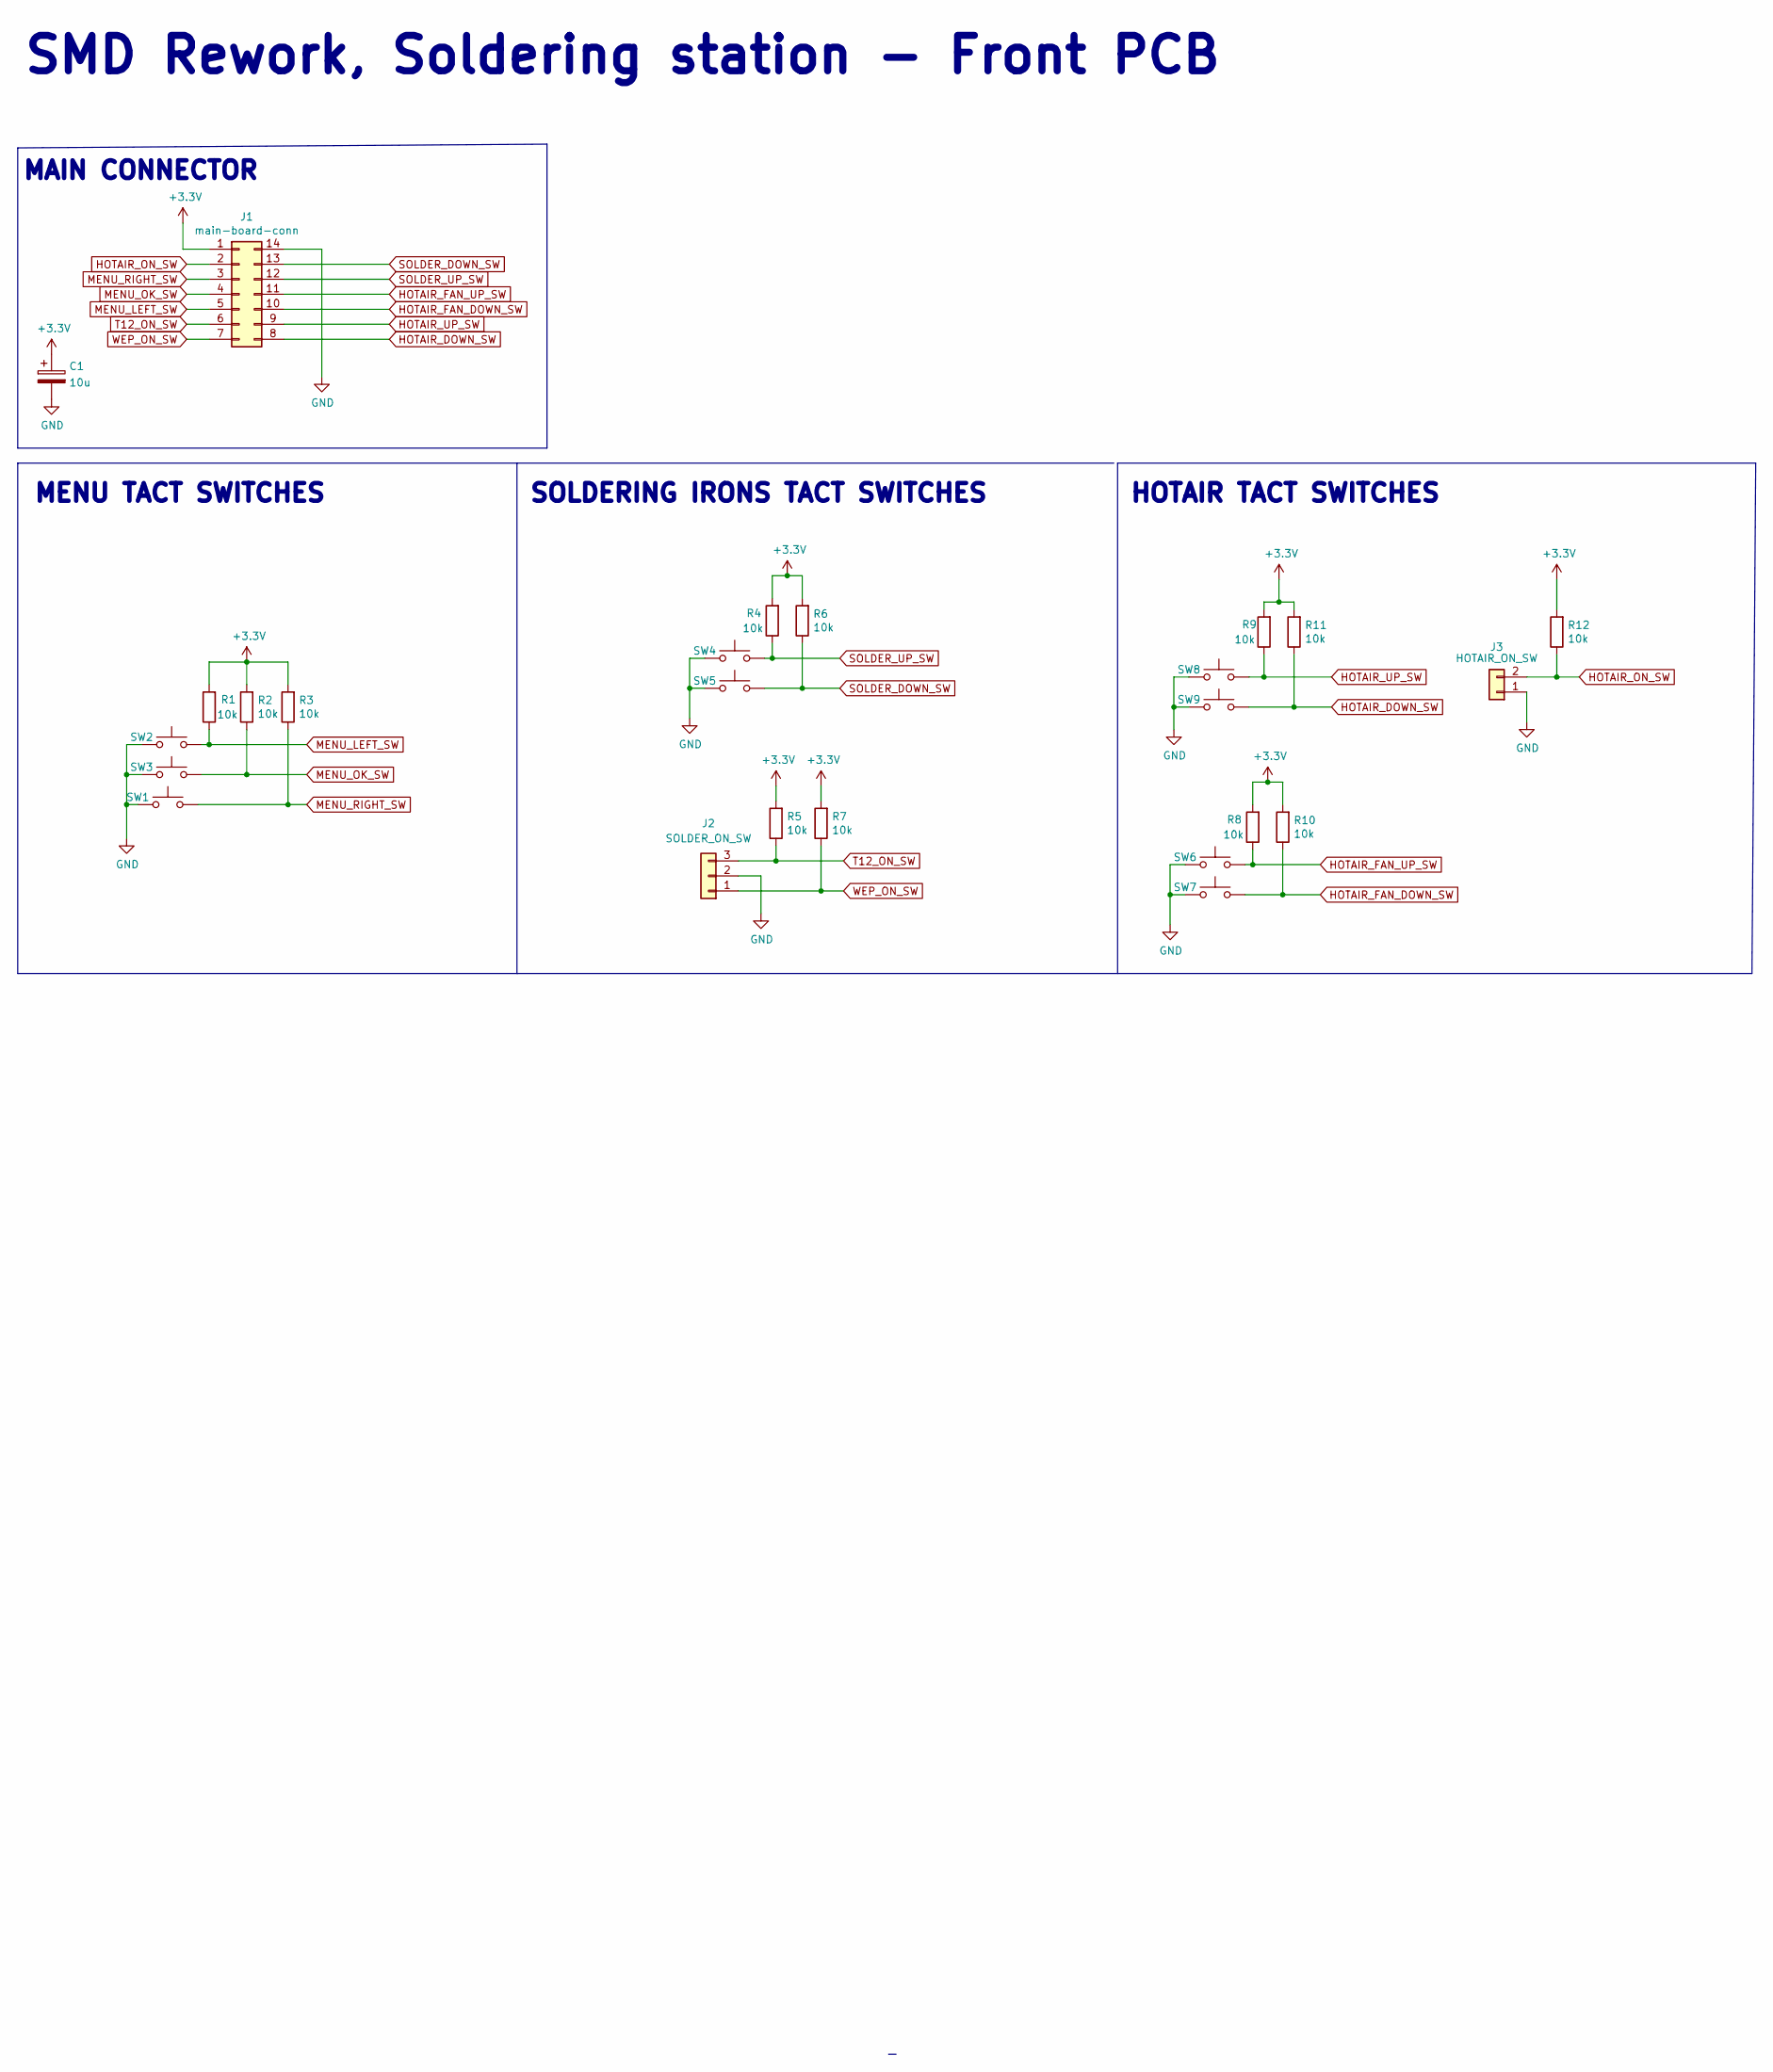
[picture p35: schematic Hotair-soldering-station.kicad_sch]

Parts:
C1: 10u; CP_Tantalum_Case-B_EIA-3528-21_Hand
J1: main-board-conn; IDC-Header_2x07_P2.54mm_Vertical
J2: SOLDER_ON_SW; PinHeader_1x03_P2.54mm_Vertical
J3: HOTAIR_ON_SW; PinHeader_1x02_P2.54mm_Vertical
R1, R2, R3, R4, R5, R6, R7, R8, R9, R10, R11, R12: 10k; 0805
SW1: MENU_RIGHT; TACTILE_SWITCH_PTH_12MM
SW2: MENU_LEFT; TACTILE_SWITCH_PTH_12MM
SW3: MENU_OK; TACTILE_SWITCH_PTH_12MM
SW4: SOLDER_UP_TEMP; TACTILE_SWITCH_PTH_12MM
SW5: SOLDER_DOWN_TEMP; TACTILE_SWITCH_PTH_12MM
SW6: FAN_UP; TACTILE_SWITCH_PTH_12MM
SW7: FAN_DOWN; TACTILE_SWITCH_PTH_12MM
SW8: HOTAIR_UP_TEMP; TACTILE_SWITCH_PTH_12MM
SW9: HOTAIR_DOWN_TEMP; TACTILE_SWITCH_PTH_12MM

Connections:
+3V3: C1.1, J1.1, R1.2, R2.2, R3.2, R4.2, R5.2, R6.2, R7.2, R8.2, R9.2, R10.2, R11.2, R12.2
GND: C1.2, J1.14, J2.2, J3.1, SW1.1, SW2.1, SW3.1, SW4.1, SW5.1, SW6.1, SW7.1, SW8.1, SW9.1
HOTAIR_DOWN_SW: J1.8, R11.1, SW9.2
HOTAIR_FAN_DOWN_SW: J1.10, R10.1, SW7.2
HOTAIR_FAN_UP_SW: J1.11, R8.1, SW6.2
HOTAIR_ON_SW: J1.2, J3.2, R12.1
HOTAIR_UP_SW: J1.9, R9.1, SW8.2
MENU_LEFT_SW: J1.5, R1.1, SW2.2
MENU_OK_SW: J1.4, R2.1, SW3.2
MENU_RIGHT_SW: J1.3, R3.1, SW1.2
SOLDER_DOWN_SW: J1.13, R6.1, SW5.2
SOLDER_UP_SW: J1.12, R4.1, SW4.2
T12_ON_SW: J1.6, J2.3, R5.1
WEP_ON_SW: J1.7, J2.1, R7.1

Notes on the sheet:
SMD Rework, Soldering station - Front PCB
SOLDERING IRONS TACT SWITCHES
MAIN CONNECTOR
MENU TACT SWITCHES
HOTAIR TACT SWITCHES

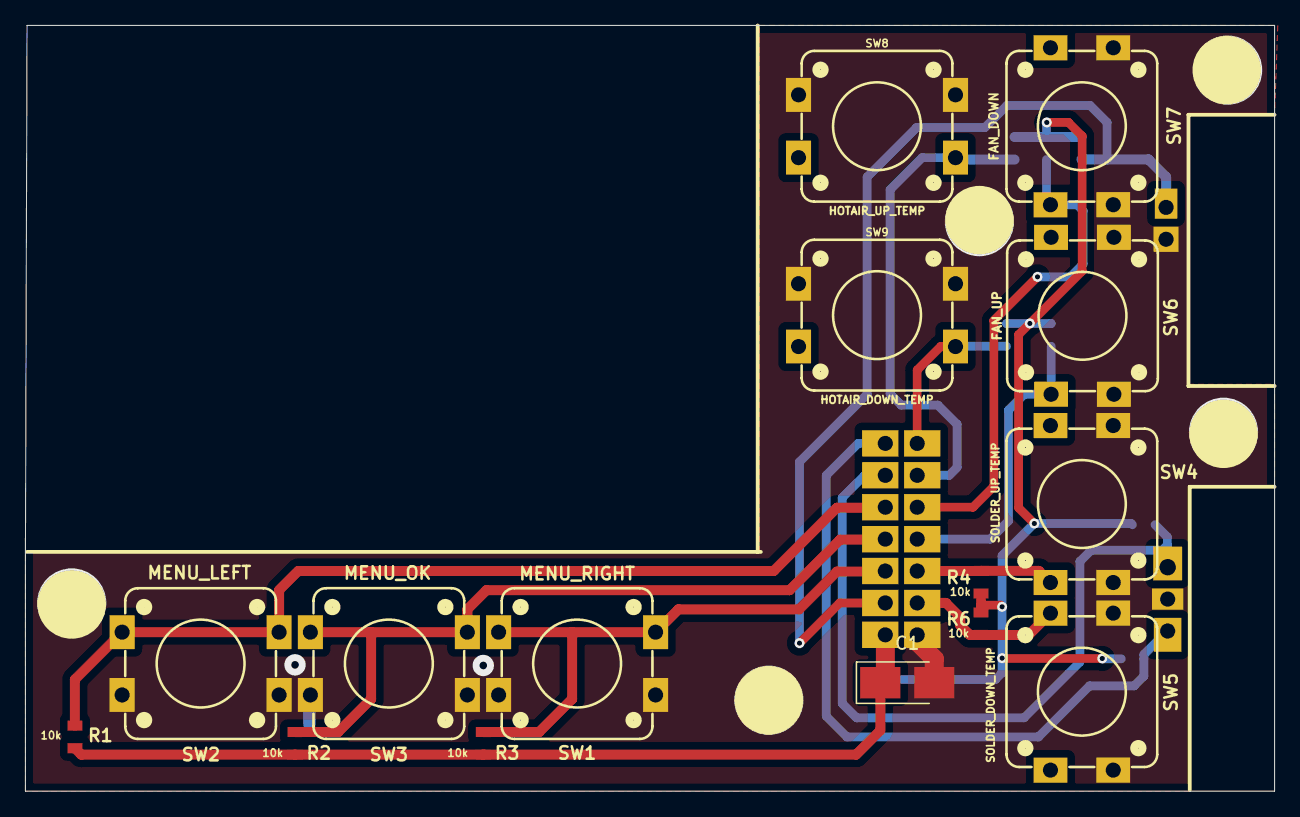
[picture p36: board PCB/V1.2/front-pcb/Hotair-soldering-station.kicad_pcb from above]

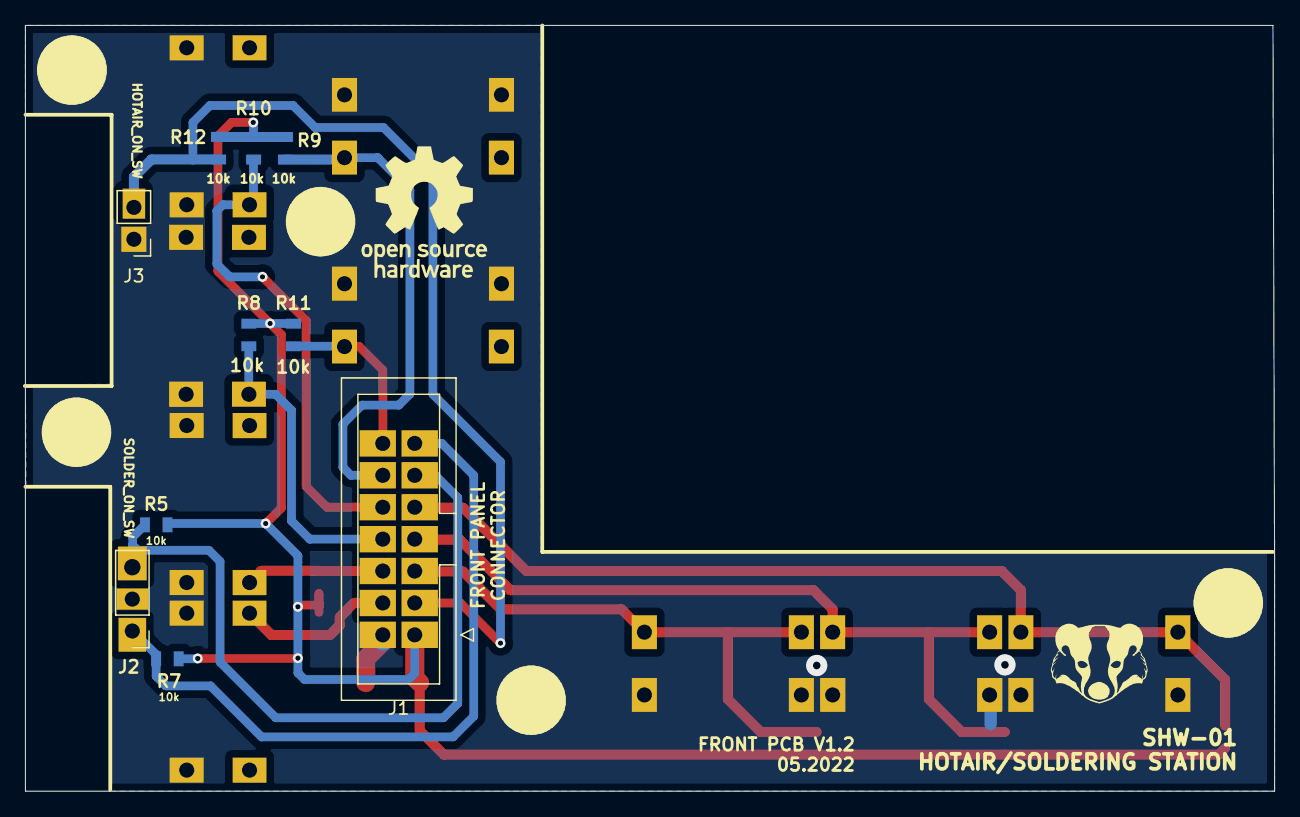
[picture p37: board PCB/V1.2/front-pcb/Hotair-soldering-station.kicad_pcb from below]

Board: 2 copper layers, 99.4 x 61.0 mm, 25 parts (10 on the bottom side), 14 nets.

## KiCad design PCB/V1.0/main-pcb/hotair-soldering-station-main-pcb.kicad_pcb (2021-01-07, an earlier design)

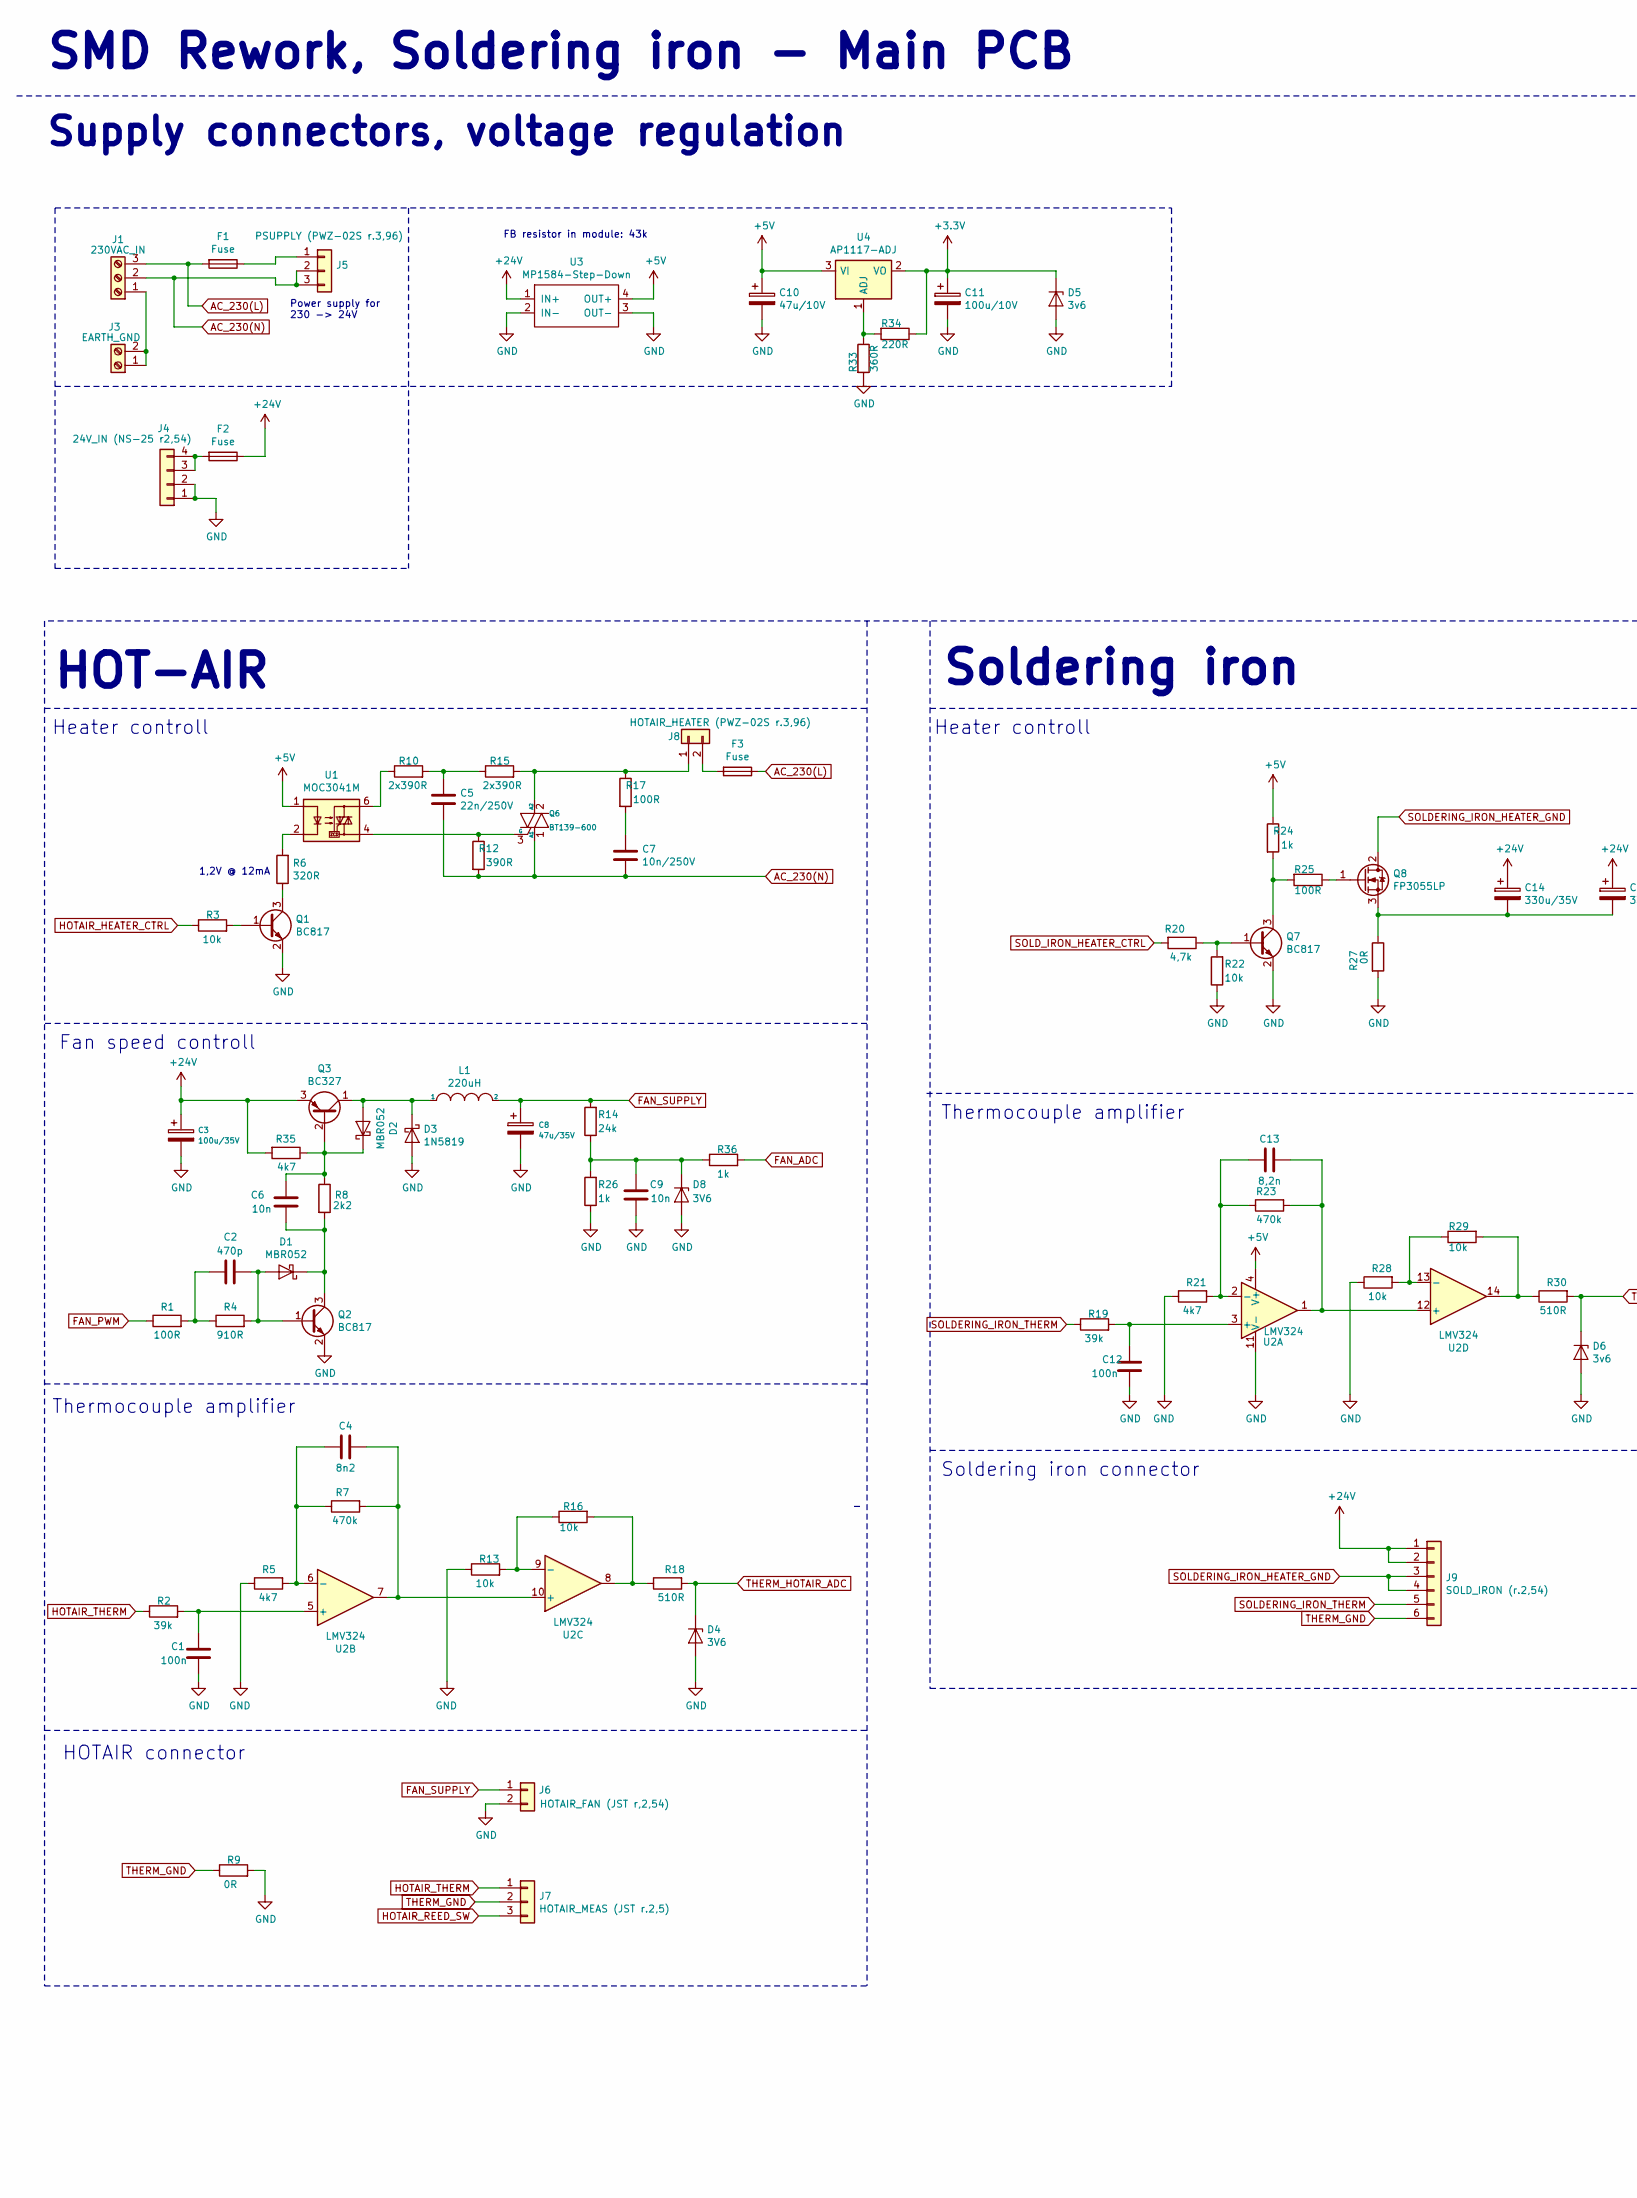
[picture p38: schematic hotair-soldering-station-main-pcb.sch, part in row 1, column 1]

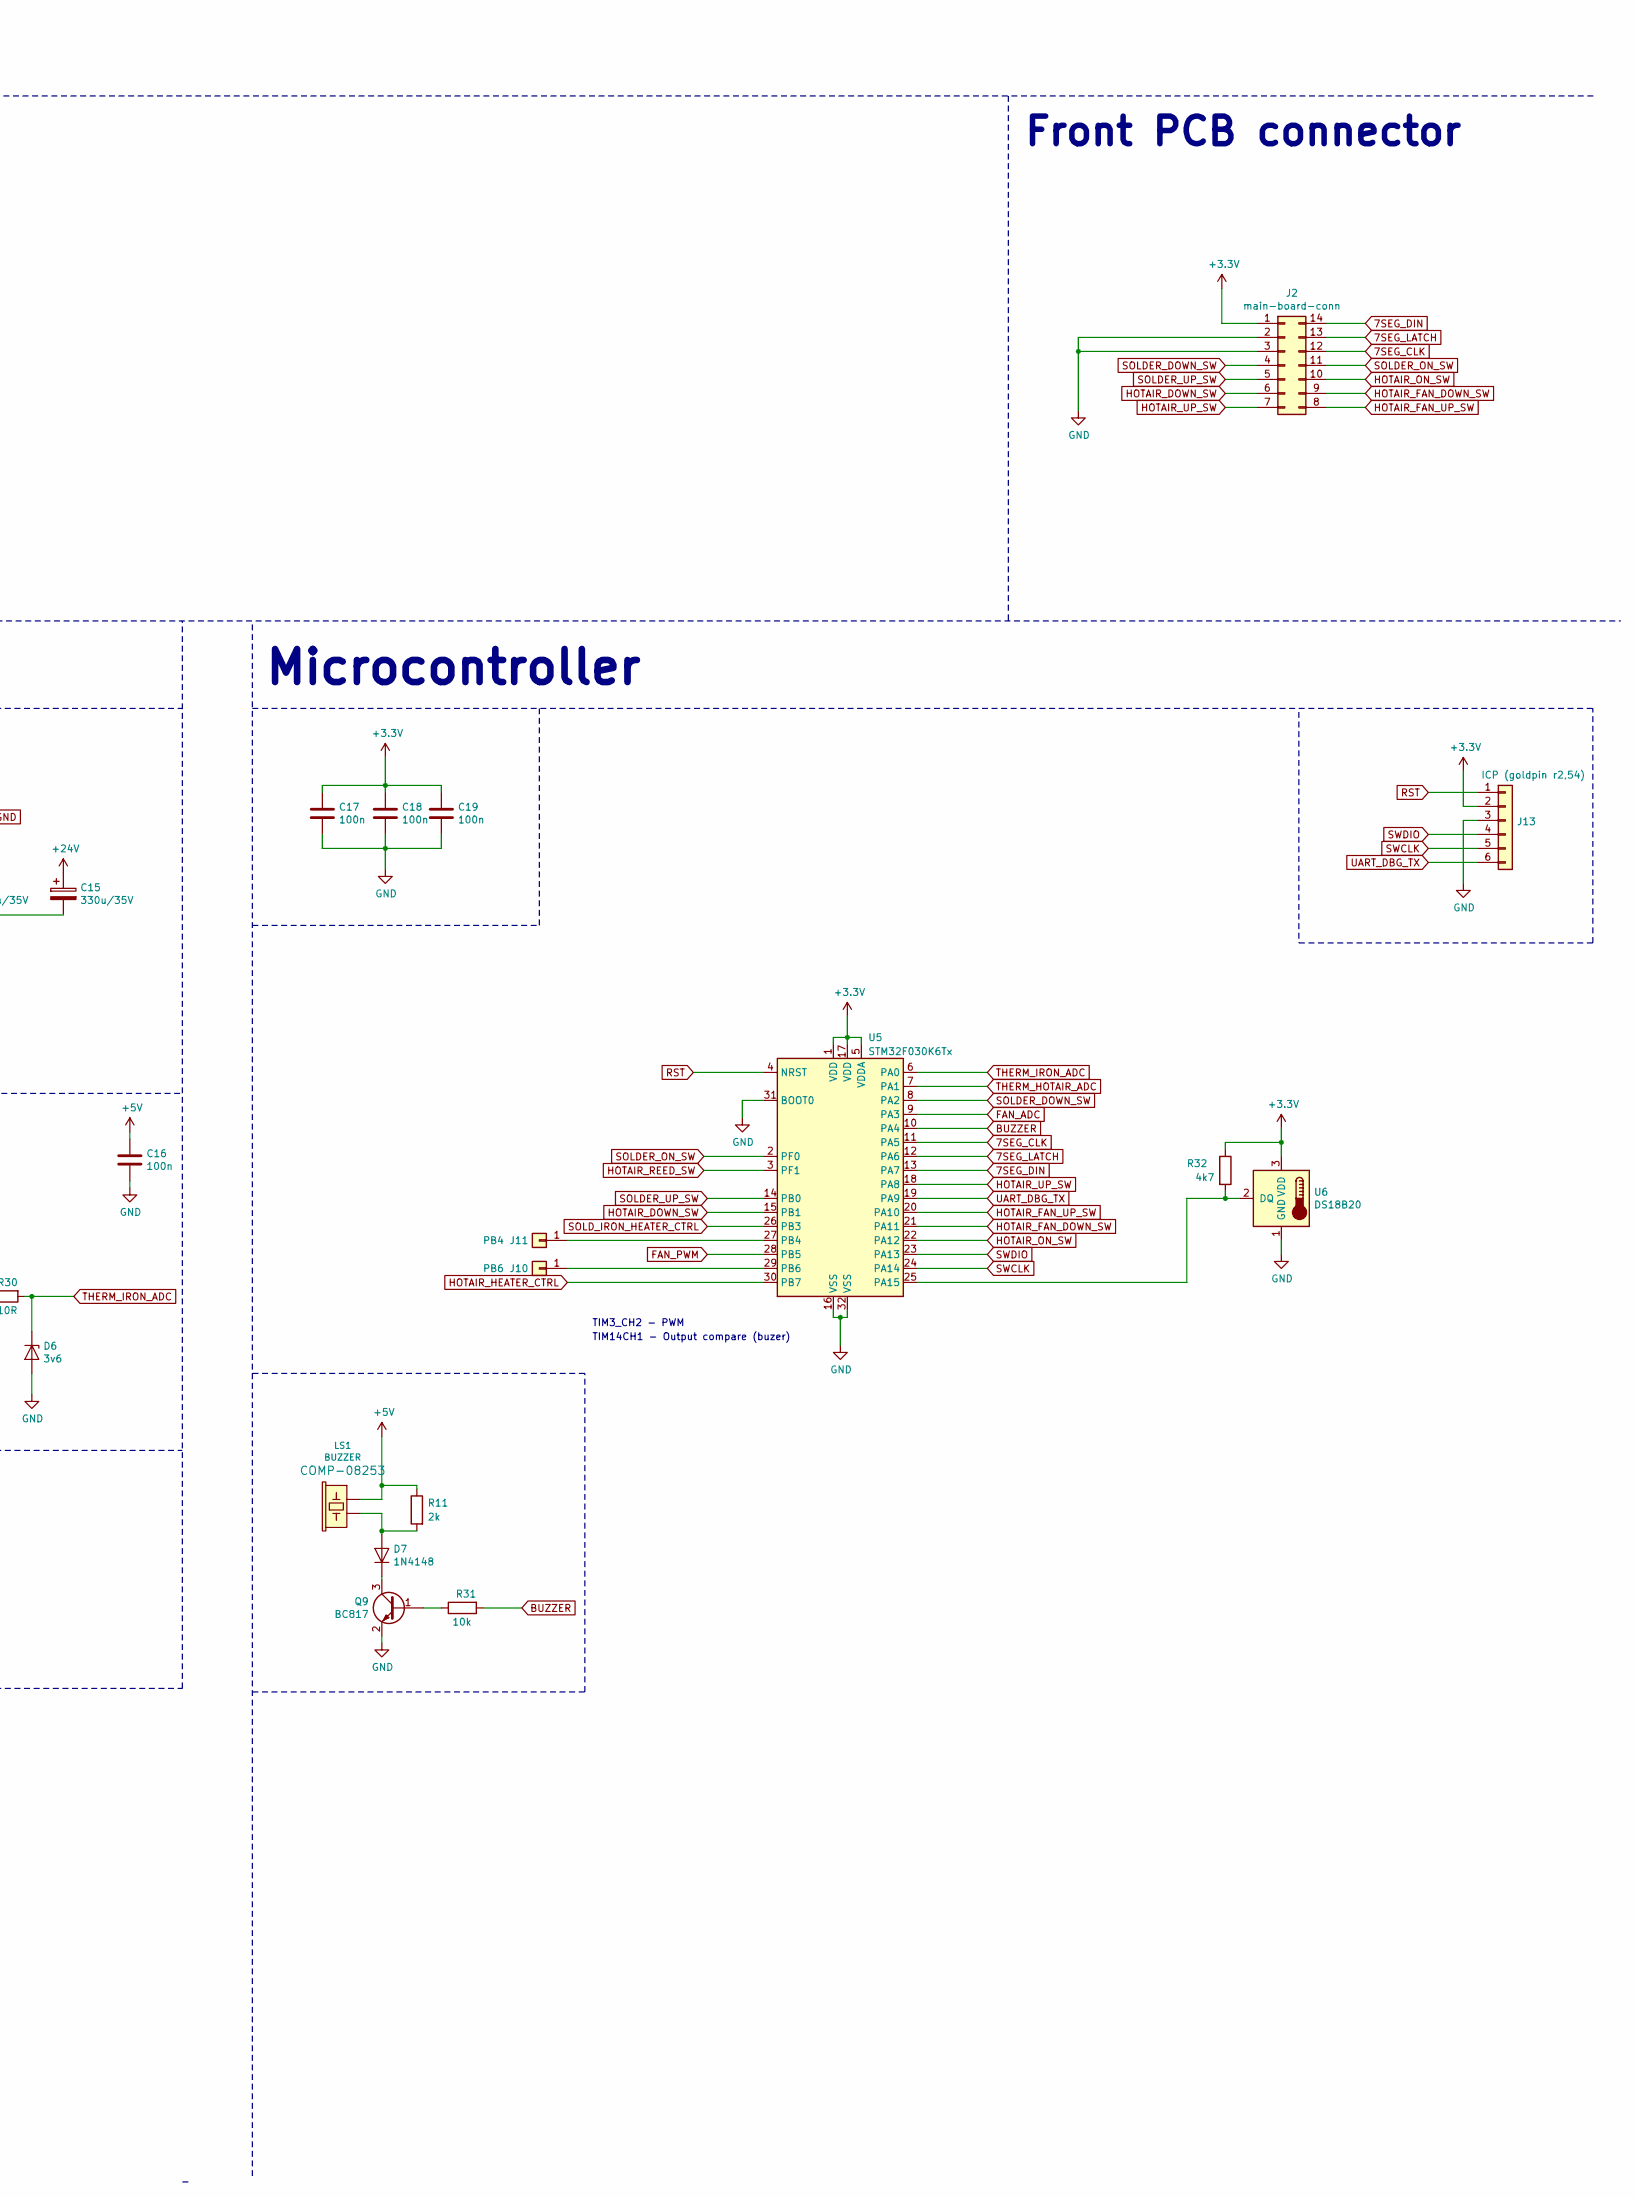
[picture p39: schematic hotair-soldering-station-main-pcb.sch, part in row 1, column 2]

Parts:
C1, C12, C16: 100n; 0805
C2: 470p; 0805
C3: 100u/35V; CP_Radial_D6.3mm_P2.50mm
C4: 8n2; 0805
C5: 22n/250V; C_Rect_L13.0mm_W5.0mm_P10.00mm_FKS3_FKP3_MKS4
C6, C9: 10n; 0805
C7: 10n/250V; C_Rect_L18.0mm_W5.0mm_P15.00mm_FKS3_FKP3
C8: 47u/35V; CP_Radial_D6.3mm_P2.50mm
C10: 47u/10V; CP_Radial_D5.0mm_P2.00mm
C11: 100u/10V; CP_Radial_D5.0mm_P2.00mm
C13: 8,2n; 0805
C14, C15: 330u/35V; CP_Radial_D10.0mm_P5.00mm
C17, C18, C19: 100n; 0603
D1, D2: MBR052; D_SOD-123
D3: 1N5819; D_MELF
D4, D8: 3V6; D_MiniMELF
D5: 3v6; D_DO-41_SOD81_P10.16mm_Horizontal
D6: 3v6; D_MiniMELF
D7: 1N4148; D_MiniMELF
F1, F2, F3: Fuse; Fuseholder5x20_horiz_SemiClosed_Casing10x25mm
J1: 230VAC_IN; Screw-Terminal-5.00mm-3pin
J2: main-board-conn; Conn-01x14
J3: EARTH_GND; Screw-Terminal-5.00mm-2pin
J4: 24V_IN (NS-25 r2,54); Conn-01x04-N25-W4P
J5: PSUPPLY (PWZ-02S r.3,96); Hirose_DF63-3P-3.96DSA_03x3.96mm_Straight
J6: HOTAIR_FAN (JST r,2,54); JST_XH_B02B-XH-A_02x2.50mm_Straight
J7: HOTAIR_MEAS (JST r.2,5); JST_XH_B03B-XH-A_03x2.50mm_Straight
J8: HOTAIR_HEATER (PWZ-02S r.3,96); Hirose_DF63-2P-3.96DSA_02x3.96mm_Straight
J9: SOLD_IRON (r.2,54); Conn-01x06-N25-W6P
J10: PB6; WIRE_PAD_1,3mm
J11: PB4; WIRE_PAD_1,3mm
J13: ICP (goldpin r2,54); Conn-01x06
L1: 220uH; L_Radial_D10.0mm_P5.00mm_Fastron_07M
LS1: BUZZER; Buzzer
Q1, Q2, Q7, Q9: BC817; SOT-23
Q3: BC327; TO-92_Inline_Wide
Q6: BT139-600; TO-220-3_Vertical
Q8: FP3055LP; TO-220-3_Vertical
R1, R25: 100R; 0805
R2, R19: 39k; 0805
R3, R13, R16, R22, R28, R29, R31: 10k; 0805
R4: 910R; 0805
R5, R21, R32, R35: 4k7; 0805
R6: 320R; 0805
R7, R23: 470k; 0805
R8: 2k2; 0805
R9, R27: 0R; 0805
R10, R15: 2x390R; R_Axial_DIN0414_L11.9mm_D4.5mm_P15.24mm_Horizontal
R11: 2k; 0805
R12: 390R; R_Axial_DIN0414_L11.9mm_D4.5mm_P15.24mm_Horizontal
R14: 24k; 0805
R17: 100R; R_Axial_DIN0414_L11.9mm_D4.5mm_P15.24mm_Horizontal
R18, R30: 510R; 0805
R20: 4,7k; 0805
R24, R26, R36: 1k; 0805
R33: 360R; 0805
R34: 220R; 0805
U1: MOC3041M; DIP-6_W7.62mm_LongPads
U2: LMV324
U3: MP1584-Step-Down; MP1584_Mini_3A_Step_Down_Conv
U4: AP1117-ADJ; SOT-223-3_TabPin2
U5: STM32F030K6Tx; LQFP-32_7x7mm_P0.8mm
U6: DS18B20; TO-92_Inline_Wide

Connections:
7SEG_CLK: J2.12, U5.11 (PA5)
7SEG_DIN: J2.14, U5.13 (PA7)
7SEG_LATCH: J2.13, U5.12 (PA6)
+3V3: C11.1, C17.1, C18.1, C19.1, D5.1 (K), J2.1, J13.2, R32.1, R34.1, U4.2 (VO), U5.1 (VDD), U5.5 (VDDA), U5.17 (VDD), U6.3 (VDD)
+5V: C10.1, C16.1, LS1.- (2), R11.1, R24.1, U1.1, U2.4 (V+), U3.4 (OUT+), U4.3 (VI)
+24V: C3.1, C14.1, C15.1, F2.1, J9.1, J9.2, Q3.3 (E), R35.2, U3.1 (IN+)
AC_230(L): F1.2, F3.1, J1.3
AC_230(N): C5.2, C7.2, J1.2, J5.2, J5.3, Q6.1 (A1), R12.2
BUZZER: R31.2, U5.10 (PA4)
FAN_ADC: R36.2, U5.9 (PA3)
FAN_PWM: R1.1, U5.28 (PB5)
FAN_SUPPLY: C8.1, J6.1, L1.2, R14.2
GND: C1.2, C3.2, C8.2, C9.1, C10.2, C11.2, C12.2, C16.2, C17.2, C18.2, C19.2, D3.2 (A), D4.2 (A), D5.2 (A), D6.2 (A), D8.2 (A), J2.2, J2.3, J4.1, J4.2, J6.2, J13.3, Q1.2 (E), Q2.2 (E), Q7.2 (E), Q9.2 (E), R5.1, R9.2, R13.1, R21.1, R22.1, R26.1, R27.2, R28.1, R33.2, U2.11 (V-), U3.2 (IN-), U3.3 (OUT-), U5.16 (VSS), U5.31 (BOOT0), U5.32 (VSS), U6.1 (GND)
HOTAIR_DOWN_SW: J2.6, U5.15 (PB1)
HOTAIR_FAN_DOWN_SW: J2.9, U5.21 (PA11)
HOTAIR_FAN_UP_SW: J2.8, U5.20 (PA10)
HOTAIR_HEATER_CTRL: R3.1, U5.30 (PB7)
HOTAIR_ON_SW: J2.10, U5.22 (PA12)
HOTAIR_REED_SW: J7.3, U5.3 (PF1)
HOTAIR_THERM: J7.1, R2.1
HOTAIR_UP_SW: J2.7, U5.18 (PA8)
unnamed: C1.1, R2.2, U2.5 (+)
unnamed: C2.1, D1.2 (A), Q2.1 (B), R4.2
unnamed: C2.2, R1.2, R4.1
unnamed: C4.1, R7.2, U2.7, U2.10 (+)
unnamed: C4.2, R5.2, R7.1, U2.6 (-)
unnamed: C5.1, R10.2, R15.1
unnamed: C6.1, D1.1 (K), Q2.3 (C), R8.2
unnamed: C6.2, D2.1 (K), Q3.2 (B), R8.1, R35.1
unnamed: C7.1, R17.2
unnamed: C9.2, D8.1 (K), R14.1, R26.2, R36.1
unnamed: C12.1, R19.2, U2.3 (+)
unnamed: C13.1, R23.2, U2.1, U2.12 (+)
unnamed: C13.2, R21.2, R23.1, U2.2 (-)
unnamed: C14.2, C15.2, Q8.3 (S), R27.1
unnamed: D2.2 (A), D3.1 (K), L1.1, Q3.1 (C)
unnamed: D7.1 (K), Q9.3 (C)
unnamed: D7.2 (A), LS1.+ (1), R11.2
unnamed: F1.1, J5.1
unnamed: F2.2, J4.3, J4.4
unnamed: F3.2, J8.2
unnamed: J1.1, J3.1, J3.2
unnamed: J8.1, Q6.2 (A2), R15.2, R17.1
unnamed: J10.1, U5.29 (PB6)
unnamed: J11.1, U5.27 (PB4)
unnamed: Q1.1 (B), R3.2
unnamed: Q1.3 (C), R6.1
unnamed: Q6.3 (G), R12.1, U1.4
unnamed: Q7.1 (B), R20.1, R22.2
unnamed: Q7.3 (C), R24.2, R25.2
unnamed: Q8.1 (G), R25.1
unnamed: Q9.1 (B), R31.1
unnamed: R6.2, U1.2
unnamed: R10.1, U1.6
unnamed: R13.2, R16.1, U2.9 (-)
unnamed: R16.2, R18.1, U2.8
unnamed: R28.2, R29.1, U2.13 (-)
unnamed: R29.2, R30.1, U2.14
unnamed: R32.2, U5.25 (PA15), U6.2 (DQ)
unnamed: R33.1, R34.2, U4.1 (ADJ)
RST: J13.1, U5.4 (NRST)
SOLDERING_IRON_HEATER_GND: J9.3, J9.4, Q8.2 (D)
SOLDERING_IRON_THERM: J9.5, R19.1
SOLDER_DOWN_SW: J2.4, U5.8 (PA2)
SOLDER_ON_SW: J2.11, U5.2 (PF0)
SOLDER_UP_SW: J2.5, U5.14 (PB0)
SOLD_IRON_HEATER_CTRL: R20.2, U5.26 (PB3)
SWCLK: J13.5, U5.24 (PA14)
SWDIO: J13.4, U5.23 (PA13)
THERM_GND: J7.2, J9.6, R9.1
THERM_HOTAIR_ADC: D4.1 (K), R18.2, U5.7 (PA1)
THERM_IRON_ADC: D6.1 (K), R30.2, U5.6 (PA0)
UART_DBG_TX: J13.6, U5.19 (PA9)

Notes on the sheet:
SMD Rework, Soldering iron - Main PCB
1,2V @ 12mA
Soldering iron
HOT-AIR
Front PCB connector
Thermocouple amplifier
Heater controll
Soldering iron connector
HOTAIR connector
Microcontroller
Fan speed controll
Supply connectors, voltage regulation
Power supply for 230 -> 24V
TIM3_CH2 - PWM
TIM14CH1 - Output compare (buzer)
FB resistor in module: 43k

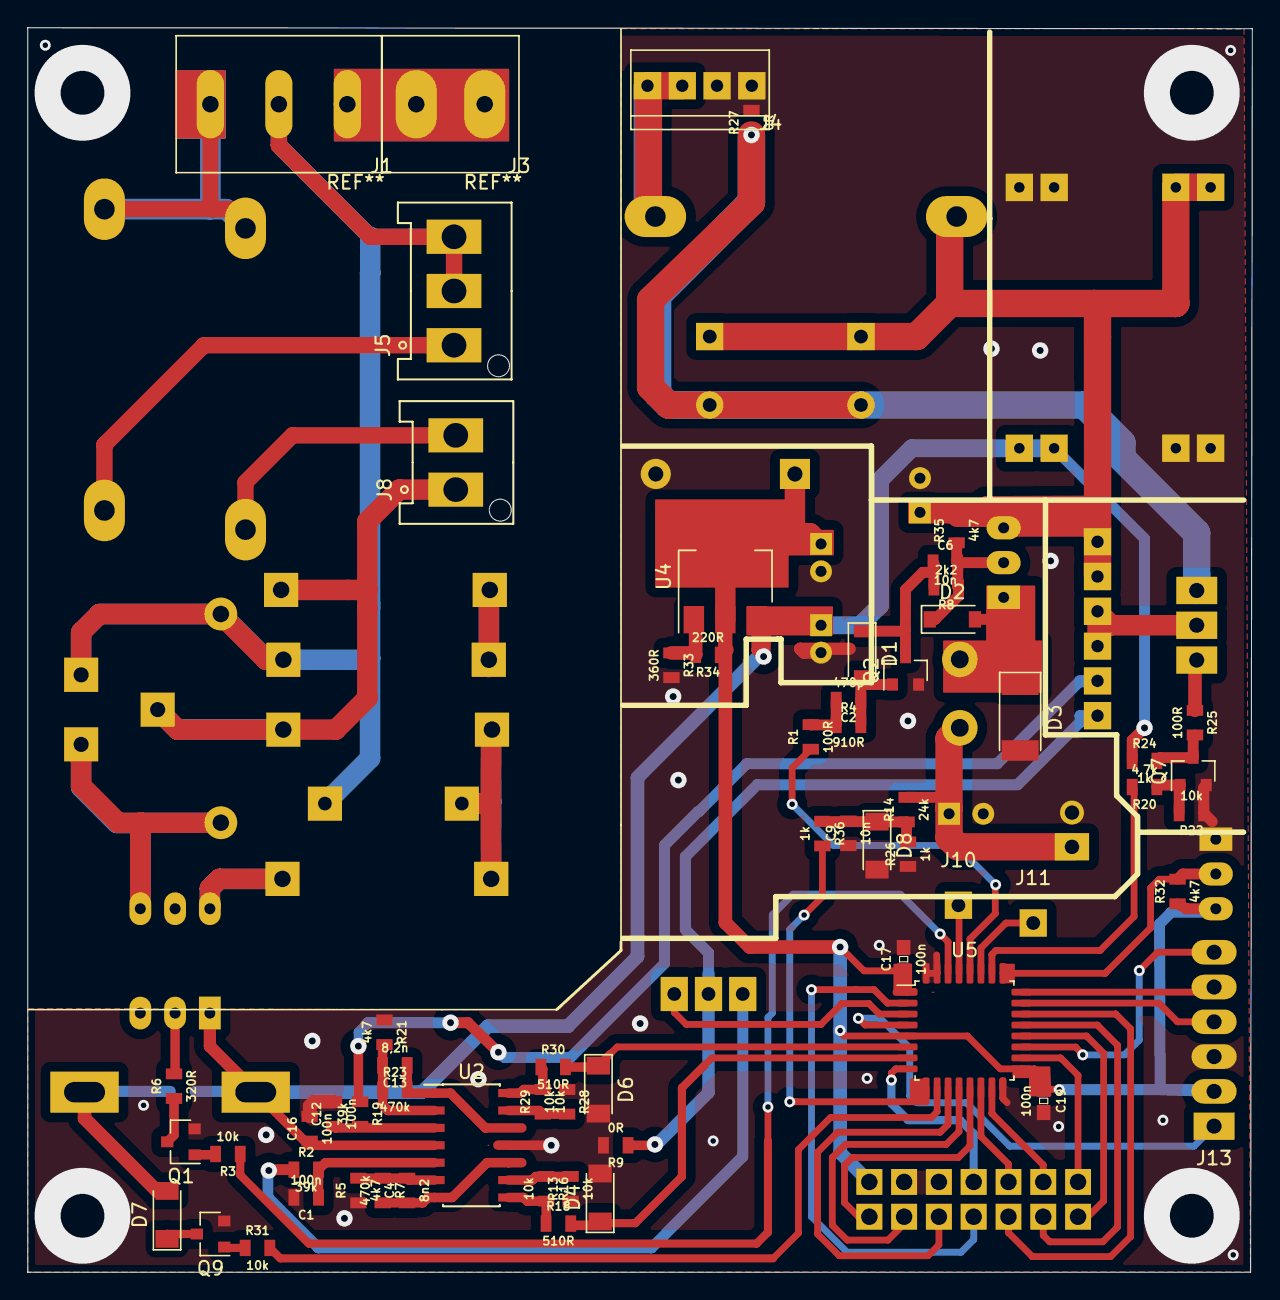
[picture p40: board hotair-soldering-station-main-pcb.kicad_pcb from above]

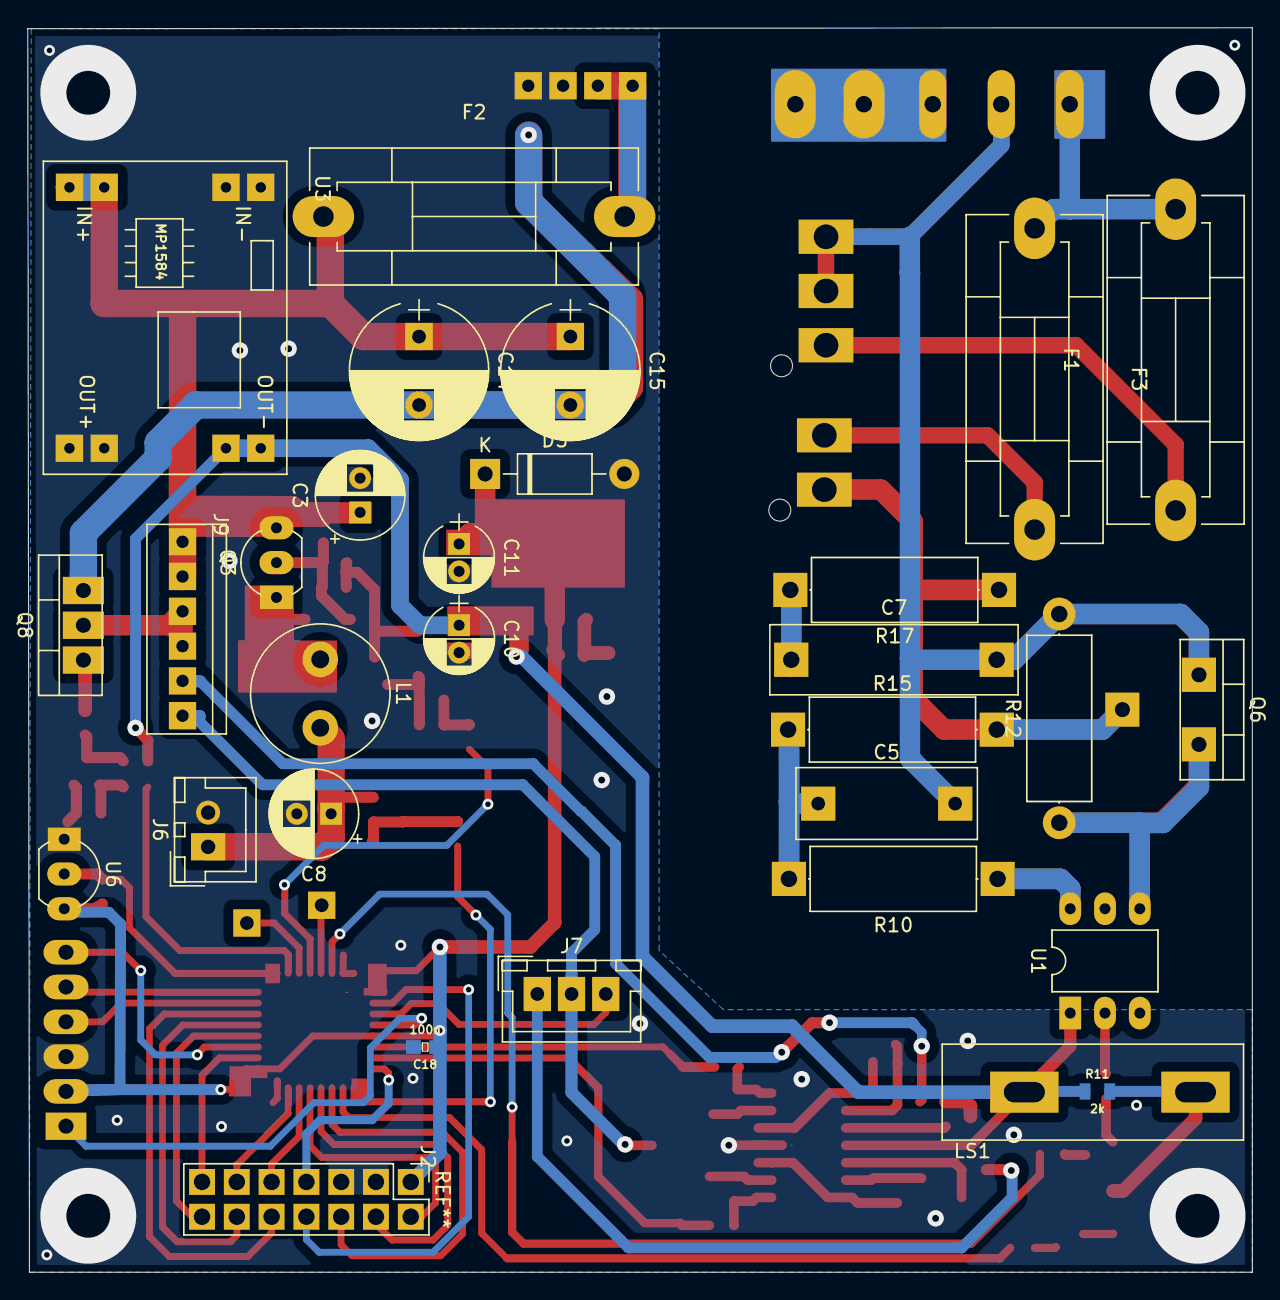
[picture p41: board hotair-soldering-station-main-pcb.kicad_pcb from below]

Board: 2 copper layers, 89.4 x 90.9 mm, 93 parts (30 on the bottom side), 73 nets.

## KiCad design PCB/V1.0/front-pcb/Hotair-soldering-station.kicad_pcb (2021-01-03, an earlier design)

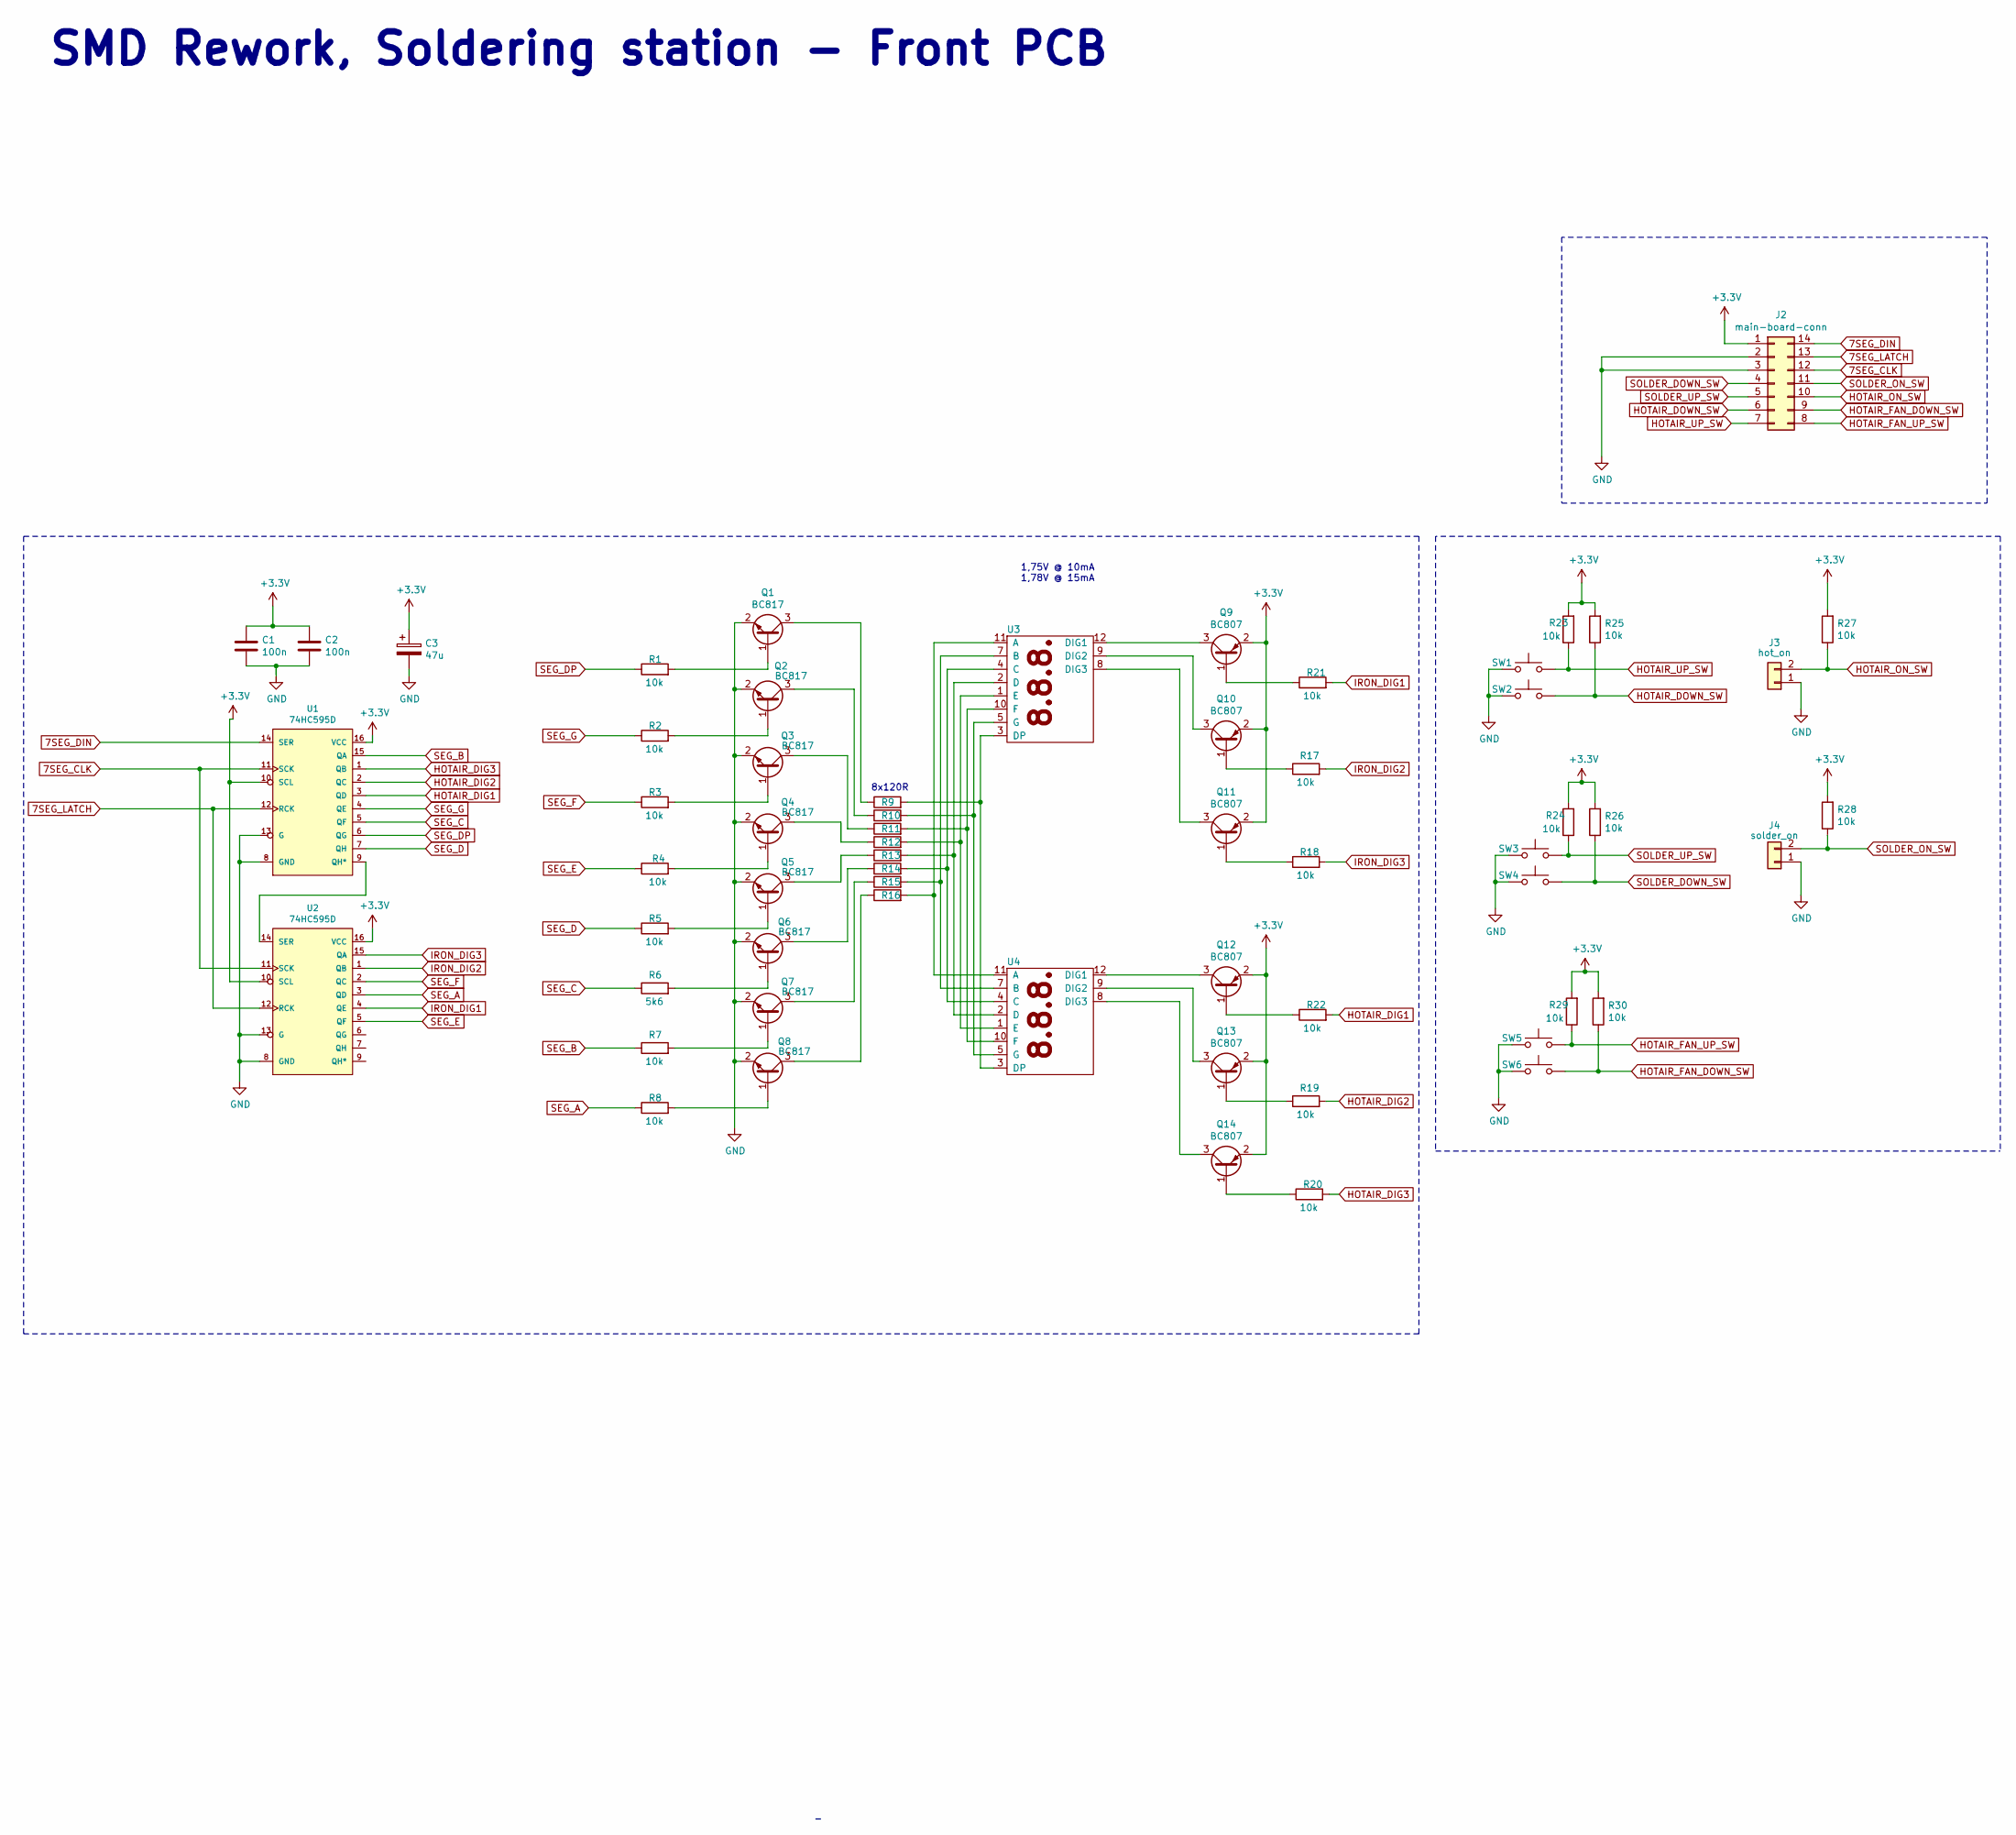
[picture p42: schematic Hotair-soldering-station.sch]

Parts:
C1, C2: 100n; 0805
C3: 47u; CP_EIA-3528-21_Kemet-B
J2: main-board-conn; Con-01x14
J3: hot_on; PinHeader_1x02_P2.54mm_Vertical
J4: solder_on; PinHeader_1x02_P2.54mm_Vertical
Q1, Q2, Q3, Q4, Q5, Q6, Q7, Q8: BC817; SOT-23
Q9, Q10, Q11, Q12, Q13, Q14: BC807; SOT-23
R1, R2, R3, R4, R5, R7, R8, R17, R18, R19, R20, R21, R22, R23, R24, R25, R26, R27, R28, R29, R30: 10k; 0805
R6: 5k6; 0805
R9, R10, R11, R12, R13, R14, R15, R16: 120R; 0805
SW1: HOTAIR_UP; TACTILE_SWITCH_PTH_12MM
SW2: HOTAIR_DOWN; TACTILE_SWITCH_PTH_12MM
SW3, SW5: SIRON_UP; TACTILE_SWITCH_PTH_12MM
SW4, SW6: SIRON_DOWN; TACTILE_SWITCH_PTH_12MM
U1, U2: 74HC595D; SO16
U3: My-Footprints:3-digit-7-segment-display; 3-digit-7-segment-display
U4: 3-dig-7-seg-display-common-anode; 3-digit-7-segment-display

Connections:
7SEG_CLK: J2.12, U1.11 (SCK), U2.11 (SCK)
7SEG_DIN: J2.14, U1.14 (SER)
7SEG_LATCH: J2.13, U1.12 (RCK), U2.12 (RCK)
+3V3: C1.1, C2.1, C3.1, J2.1, Q9.2 (E), Q10.2 (E), Q11.2 (E), Q12.2 (E), Q13.2 (E), Q14.2 (E), R23.2, R24.2, R25.2, R26.2, R27.2, R28.2, R29.2, R30.2, U1.10 (SCL), U1.16 (VCC), U2.10 (SCL), U2.16 (VCC)
GND: C1.2, C2.2, C3.2, J2.2, J2.3, J3.1, J4.1, Q1.2 (E), Q2.2 (E), Q3.2 (E), Q4.2 (E), Q5.2 (E), Q6.2 (E), Q7.2 (E), Q8.2 (E), SW1.1, SW2.1, SW3.1, SW4.1, SW5.1, SW6.1, U1.8 (GND), U1.13 (G), U2.8 (GND), U2.13 (G)
HOTAIR_DIG1: R22.2, U1.3 (QD)
HOTAIR_DIG2: R19.2, U1.2 (QC)
HOTAIR_DIG3: R20.2, U1.1 (QB)
HOTAIR_DOWN_SW: J2.6, R25.1, SW2.2
HOTAIR_FAN_DOWN_SW: J2.9, R30.1, SW6.2
HOTAIR_FAN_UP_SW: J2.8, R29.1, SW5.2
HOTAIR_ON_SW: J2.10, J3.2, R27.1
HOTAIR_UP_SW: J2.7, R23.1, SW1.2
IRON_DIG1: R21.2, U2.4 (QE)
IRON_DIG2: R17.2, U2.1 (QB)
IRON_DIG3: R18.2, U2.15 (QA)
unnamed: Q1.1 (B), R1.2
unnamed: Q1.3 (C), R9.1
unnamed: Q2.1 (B), R2.2
unnamed: Q2.3 (C), R10.1
unnamed: Q3.1 (B), R3.2
unnamed: Q3.3 (C), R11.1
unnamed: Q4.1 (B), R4.2
unnamed: Q4.3 (C), R12.1
unnamed: Q5.1 (B), R5.2
unnamed: Q5.3 (C), R13.1
unnamed: Q6.1 (B), R6.2
unnamed: Q6.3 (C), R14.1
unnamed: Q7.1 (B), R7.2
unnamed: Q7.3 (C), R15.1
unnamed: Q8.1 (B), R8.2
unnamed: Q8.3 (C), R16.1
unnamed: Q9.1 (B), R21.1
unnamed: Q9.3 (C), U3.12 (DIG1)
unnamed: Q10.1 (B), R17.1
unnamed: Q10.3 (C), U3.9 (DIG2)
unnamed: Q11.1 (B), R18.1
unnamed: Q11.3 (C), U3.8 (DIG3)
unnamed: Q12.1 (B), R22.1
unnamed: Q12.3 (C), U4.12 (DIG1)
unnamed: Q13.1 (B), R19.1
unnamed: Q13.3 (C), U4.9 (DIG2)
unnamed: Q14.1 (B), R20.1
unnamed: Q14.3 (C), U4.8 (DIG3)
unnamed: R9.2, U3.3 (DP), U4.3 (DP)
unnamed: R10.2, U3.5 (G), U4.5 (G)
unnamed: R11.2, U3.10 (F), U4.10 (F)
unnamed: R12.2, U3.1 (E), U4.1 (E)
unnamed: R13.2, U3.2 (D), U4.2 (D)
unnamed: R14.2, U3.4 (C), U4.4 (C)
unnamed: R15.2, U3.7 (B), U4.7 (B)
unnamed: R16.2, U3.11 (A), U4.11 (A)
unnamed: U1.9 (QH*), U2.14 (SER)
SEG_A: R8.1, U2.3 (QD)
SEG_B: R7.1, U1.15 (QA)
SEG_C: R6.1, U1.5 (QF)
SEG_D: R5.1, U1.7 (QH)
SEG_DP: R1.1, U1.6 (QG)
SEG_E: R4.1, U2.5 (QF)
SEG_F: R3.1, U2.2 (QC)
SEG_G: R2.1, U1.4 (QE)
SOLDER_DOWN_SW: J2.4, R26.1, SW4.2
SOLDER_ON_SW: J2.11, J4.2, R28.1
SOLDER_UP_SW: J2.5, R24.1, SW3.2

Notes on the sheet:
1,75V @ 10mA 1,78V @ 15mA
8x120R
SMD Rework, Soldering station - Front PCB



Board: 2 copper layers, 70.0 x 120.0 mm, 60 parts (48 on the bottom side), 64 nets.

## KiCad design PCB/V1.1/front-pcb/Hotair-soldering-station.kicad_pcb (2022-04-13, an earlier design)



Board: 2 copper layers, 99.4 x 61.0 mm, 24 parts (13 on the bottom side), 14 nets.

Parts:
J1: Conn_01x03; PinHeader_1x03_P2.54mm_Vertical
J2: main-board-conn; Con-01x14
J3: hot_on; PinHeader_1x02_P2.54mm_Vertical
R1, R2, R3, R4, R23, R24, R25, R26, R27, R28, R29, R30: 10k; 0805
SW1: HOTAIR_UP; TACTILE_SWITCH_PTH_12MM
SW2: HOTAIR_DOWN; TACTILE_SWITCH_PTH_12MM
SW3: SIRON_UP; TACTILE_SWITCH_PTH_12MM
SW4: SIRON_DOWN; TACTILE_SWITCH_PTH_12MM
SW5: FAN_UP; TACTILE_SWITCH_PTH_12MM
SW6: FAN_DOWN; TACTILE_SWITCH_PTH_12MM
SW7: MENU_UP; TACTILE_SWITCH_PTH_12MM
SW8: MENU_DOWN; TACTILE_SWITCH_PTH_12MM
SW9: MENU_OK; TACTILE_SWITCH_PTH_12MM

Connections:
+3V3: J2.1, R1.2, R2.2, R3.2, R4.2, R23.2, R24.2, R25.2, R26.2, R27.2, R28.2, R29.2, R30.2
GND: J1.2, J2.2, J3.1, SW1.1, SW2.1, SW3.1, SW4.1, SW5.1, SW6.1, SW7.1, SW8.1, SW9.1
HOTAIR_DOWN_SW: J2.8, R25.1, SW2.2
HOTAIR_FAN_DOWN_SW: J2.10, R30.1, SW6.2
HOTAIR_FAN_UP_SW: J2.11, R29.1, SW5.2
HOTAIR_ON_SW: J2.14, J3.2, R27.1
HOTAIR_UP_SW: J2.9, R23.1, SW1.2
MENU_DOWN_SW: J2.5, R1.1, SW8.2
MENU_OK_SW: J2.4, R2.1, SW9.2
MENU_UP_SW: J2.3, R3.1, SW7.2
SOLDER_DOWN_SW: J2.13, R26.1, SW4.2
SOLDER_UP_SW: J2.12, R24.1, SW3.2
T12_ON_SW: J1.3, J2.6, R28.1
WEP_ON_SW: J1.1, J2.7, R4.1

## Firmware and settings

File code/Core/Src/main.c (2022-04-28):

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
/* Includes ------------------------------------------------------------------*/
#include "main.h"
#include "cmsis_os.h"
#include "adc.h"
#include "spi.h"
#include "tim.h"
#include "usart.h"
#include "gpio.h"

/* USER CODE BEGIN Includes */
#include <stdio.h>
#include <string.h>
#include "retarget.h"
#include "LCD16x2/LCD.h"
#include "MAX31855/MAX31855.h"
#include "utils.h"
#include "test_wep.h"
#include "adc_functions.h"
#include "test_t12.h"
#include "test_buttons.h"

#include "Buttons/buttons.h"

/* USER CODE END Includes */


void SystemClock_Config(void);
void MX_FREERTOS_Init(void);
/* USER CODE BEGIN 0 */
void button_short_pressed_test()
{
	static int i = 0;
	LCD_Clear();
	char buf[12];
	snprintf(buf, 12, "BUTTON S:%d", i);
	LCD_Puts(0,0, buf);
	i++;
}

void button_long_pressed_test()
{
	static int i = 0;
	LCD_Clear();
	char buf[12];
	snprintf(buf, 12, "BUTTON L:%d", i);
	LCD_Puts(0,1, buf);
	i++;
}
/* USER CODE END 0 */

/**
  * @brief  The application entry point.
  * @retval int
  */
int main(void)
{
  /* MCU Configuration--------------------------------------------------------*/

  /* Reset of all peripherals, Initializes the Flash interface and the Systick. */
  HAL_Init();

  /* Configure the system clock */
  SystemClock_Config();

  /* Initialize all configured peripherals */
  MX_GPIO_Init();
  MX_ADC1_Init();
  MX_SPI1_Init();
  MX_TIM1_Init();
  MX_TIM2_Init();
  MX_TIM3_Init();
  MX_TIM4_Init();
  MX_USART2_UART_Init();
  /* USER CODE BEGIN 2 */
  Start_generic_timer();

  //Init printf retarget
  RetargetInit(&huart2);

  //Init LCD display
  LCD_Init();
  LCD_DisplayOn();
  LCD_Clear();

  Init_ADC();

  printf("Hello! \r\n");

  // Test buttons
  button_pressed_short_cb(BUTTON_HOTAIR_FAN_UP, button_short_pressed_test);
  button_pressed_long_cb(BUTTON_HOTAIR_FAN_DOWN, button_long_pressed_test);

  /* USER CODE END 2 */

  /* Init scheduler */
  osKernelInitialize();  /* Call init function for freertos objects (in freertos.c) */
  MX_FREERTOS_Init();

  /* Start scheduler */
  osKernelStart();

  /* We should never get here as control is now taken by the scheduler */
  /* Infinite loop */
  /* USER CODE BEGIN WHILE */

  while(1)
  {
    /* USER CODE END WHILE */

    /* USER CODE BEGIN 3 */

	 Test_WEP();
	 Test_T12();
	 Test_HOTAIR();
	 Test_Buttons();

  }
  /* USER CODE END 3 */
}

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


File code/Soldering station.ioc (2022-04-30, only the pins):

Mcu.UserName=STM32F103C8Tx
PA0-WKUP.GPIO_Label=HOTAIR_ON_SW
PA0-WKUP.Signal=GPIO_Input
PA1.GPIO_Label=HOTAIR_FAN_ADC
PA1.Signal=ADCx_IN1
PA10.GPIO_Label=HOTAIR_FAN_DOWN_SW
PA10.Signal=GPIO_Input
PA11.GPIO_Label=HOTAIR_FAN_UP_SW
PA11.Signal=GPIO_Input
PA12.GPIO_Label=HOTAIR_TEMP_UP_SW
PA12.Signal=GPIO_Input
PA13.GPIO_Label=SWDIO
PA13.Signal=SYS_JTMS-SWDIO
PA14.GPIO_Label=SWCLK
PA14.Signal=SYS_JTCK-SWCLK
PA15.GPIO_Label=BUZZER_PWM
PA15.Signal=S_TIM2_CH1_ETR
PA2.GPIO_Label=UART_DBG_TX
PA2.Signal=USART2_TX
PA3.GPIO_Label=MAX31855_IRON_CS
PA3.Signal=GPIO_Output
PA4.GPIO_Label=MAX31855_HOTAIR_CS
PA4.Signal=GPIO_Output
PA5.Signal=SPI1_SCK
PA6.Signal=SPI1_MISO
PA7.GPIO_Label=IRON_WEP_HEATER_CTRL
PA7.Signal=GPIO_Output
PA8.GPIO_Label=HOTAIR_FAN_PWM
PA8.Signal=S_TIM1_CH1
PA9.GPIO_Label=HOTAIR_HEATER_CTRL
PA9.Signal=GPIO_Output
PB0.GPIO_Label=IRON_T12_TEMP_ADC
PB0.Signal=ADCx_IN8
PB1.GPIO_Label=HOTAIR_TEMP_ADC
PB1.Signal=ADCx_IN9
PB10.GPIO_Label=MENU_RIGHT_SW
PB10.Signal=GPIO_Input
PB11.GPIO_Label=MENU_OK_SW
PB11.Signal=GPIO_Input
PB12.GPIO_Label=MENU_LEFT_SW
PB12.Signal=GPIO_Input
PB13.GPIO_Label=SOLDER_SELECT_T12_SW
PB13.Signal=GPIO_Input
PB14.GPIO_Label=IRON_T12_MOTION_SW
PB14.Signal=GPIO_Input
PB15.GPIO_Label=SOLDER_SELECT_WEP_SW
PB15.Signal=GPIO_Input
PB2.GPIO_Label=HOTAIR_REED_SW
PB2.Signal=GPIO_Input
PB3.GPIO_Label=LED_BACKLIGHT_PWM
PB3.Signal=S_TIM2_CH2
PB4.GPIO_Label=LCD_D7
PB4.Signal=GPIO_Output
PB5.GPIO_Label=LCD_D6
PB5.Signal=GPIO_Output
PB6.GPIO_Label=IRON_T12_HEATER_CTRL
PB6.Signal=S_TIM4_CH1
PB7.GPIO_Label=LCD_D5
PB7.Signal=GPIO_Output
PB8.GPIO_Label=LCD_D4
PB8.Signal=GPIO_Output
PB9.GPIO_Label=LCD_EN
PB9.Signal=GPIO_Output
PC13-TAMPER-RTC.GPIO_Label=LCD_RW
PC13-TAMPER-RTC.Signal=GPIO_Output
PC14-OSC32_IN.GPIO_Label=LCD_RS
PC14-OSC32_IN.Signal=GPIO_Output
PC15-OSC32_OUT.GPIO_Label=HOTAIR_TEMP_DOWN_SW
PC15-OSC32_OUT.Signal=GPIO_Input
PD0-OSC_IN.GPIO_Label=SOLDER_TEMP_UP_SW
PD0-OSC_IN.Signal=GPIO_Input
PD1-OSC_OUT.GPIO_Label=SOLDER_TEMP_DOWN_SW
PD1-OSC_OUT.Signal=GPIO_Input

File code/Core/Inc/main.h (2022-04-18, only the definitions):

#define LCD_RW_Pin GPIO_PIN_13
#define LCD_RW_GPIO_Port GPIOC
#define LCD_RS_Pin GPIO_PIN_14
#define LCD_RS_GPIO_Port GPIOC
#define HOTAIR_TEMP_DOWN_SW_Pin GPIO_PIN_15
#define HOTAIR_TEMP_DOWN_SW_GPIO_Port GPIOC
#define SOLDER_TEMP_UP_SW_Pin GPIO_PIN_0
#define SOLDER_TEMP_UP_SW_GPIO_Port GPIOD
#define SOLDER_TEMP_DOWN_SW_Pin GPIO_PIN_1
#define SOLDER_TEMP_DOWN_SW_GPIO_Port GPIOD
#define HOTAIR_ON_SW_Pin GPIO_PIN_0
#define HOTAIR_ON_SW_GPIO_Port GPIOA
#define HOTAIR_FAN_ADC_Pin GPIO_PIN_1
#define HOTAIR_FAN_ADC_GPIO_Port GPIOA
#define UART_DBG_TX_Pin GPIO_PIN_2
#define UART_DBG_TX_GPIO_Port GPIOA
#define MAX31855_IRON_CS_Pin GPIO_PIN_3
#define MAX31855_IRON_CS_GPIO_Port GPIOA
#define MAX31855_HOTAIR_CS_Pin GPIO_PIN_4
#define MAX31855_HOTAIR_CS_GPIO_Port GPIOA
#define IRON_WEP_HEATER_CTRL_Pin GPIO_PIN_7
#define IRON_WEP_HEATER_CTRL_GPIO_Port GPIOA
#define IRON_T12_TEMP_ADC_Pin GPIO_PIN_0
#define IRON_T12_TEMP_ADC_GPIO_Port GPIOB
#define HOTAIR_TEMP_ADC_Pin GPIO_PIN_1
#define HOTAIR_TEMP_ADC_GPIO_Port GPIOB
#define HOTAIR_REED_SW_Pin GPIO_PIN_2
#define HOTAIR_REED_SW_GPIO_Port GPIOB
#define MENU_RIGHT_SW_Pin GPIO_PIN_10
#define MENU_RIGHT_SW_GPIO_Port GPIOB
#define MENU_OK_SW_Pin GPIO_PIN_11
#define MENU_OK_SW_GPIO_Port GPIOB
#define MENU_LEFT_SW_Pin GPIO_PIN_12
#define MENU_LEFT_SW_GPIO_Port GPIOB
#define SOLDER_SELECT_T12_SW_Pin GPIO_PIN_13
#define SOLDER_SELECT_T12_SW_GPIO_Port GPIOB
#define IRON_T12_MOTION_SW_Pin GPIO_PIN_14
#define IRON_T12_MOTION_SW_GPIO_Port GPIOB
#define SOLDER_SELECT_WEP_SW_Pin GPIO_PIN_15
#define SOLDER_SELECT_WEP_SW_GPIO_Port GPIOB
#define HOTAIR_FAN_PWM_Pin GPIO_PIN_8
#define HOTAIR_FAN_PWM_GPIO_Port GPIOA
#define HOTAIR_HEATER_CTRL_Pin GPIO_PIN_9
#define HOTAIR_HEATER_CTRL_GPIO_Port GPIOA
#define HOTAIR_FAN_DOWN_SW_Pin GPIO_PIN_10
#define HOTAIR_FAN_DOWN_SW_GPIO_Port GPIOA
#define HOTAIR_FAN_UP_SW_Pin GPIO_PIN_11
#define HOTAIR_FAN_UP_SW_GPIO_Port GPIOA
#define HOTAIR_TEMP_UP_SW_Pin GPIO_PIN_12
#define HOTAIR_TEMP_UP_SW_GPIO_Port GPIOA
#define SWDIO_Pin GPIO_PIN_13
#define SWDIO_GPIO_Port GPIOA
#define SWCLK_Pin GPIO_PIN_14
#define SWCLK_GPIO_Port GPIOA
#define BUZZER_PWM_Pin GPIO_PIN_15
#define BUZZER_PWM_GPIO_Port GPIOA
#define LED_BACKLIGHT_PWM_Pin GPIO_PIN_3
#define LED_BACKLIGHT_PWM_GPIO_Port GPIOB
#define LCD_D7_Pin GPIO_PIN_4
#define LCD_D7_GPIO_Port GPIOB
#define LCD_D6_Pin GPIO_PIN_5
#define LCD_D6_GPIO_Port GPIOB
#define IRON_T12_HEATER_CTRL_Pin GPIO_PIN_6
#define IRON_T12_HEATER_CTRL_GPIO_Port GPIOB
#define LCD_D5_Pin GPIO_PIN_7
#define LCD_D5_GPIO_Port GPIOB
#define LCD_D4_Pin GPIO_PIN_8
#define LCD_D4_GPIO_Port GPIOB
#define LCD_EN_Pin GPIO_PIN_9
#define LCD_EN_GPIO_Port GPIOB

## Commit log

2020-10-03 Schematic add fan regulator, 7seg display, push button
    [Hotair-soldering-station.kicad_pcb, Hotair-soldering-station.sch]
2020-10-04 front schematic done, main schematic add AC circuit
    [Hotair-soldering-station.kicad_pcb, Hotair-soldering-station.sch, hotair-soldering-station-main-pcb.kicad_pcb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]
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2020-10-07 add heater controll circuit, add sch block structure
    [Hotair-soldering-station.sch, hotair-soldering-station-main-pcb.sch]
2020-10-09 main schematic update, front pcb routing
    [Hotair-soldering-station.kicad_pcb, Hotair-soldering-station.sch, hotair-soldering-station-main-pcb.sch]
2020-10-10 Draw main PCB digital schematic parts, add footprints, connectors unification
    [hotair-soldering-station-main-pcb.sch]
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2020-10-19 add hot air fan buttons
    [Hotair-soldering-station.kicad_pcb, Hotair-soldering-station.sch]
2020-11-05 front PCB - finish
    [Hotair-soldering-station.kicad_pcb, Hotair-soldering-station.sch]
2020-11-05 main pcb smsps fan add
    [Hotair-soldering-station.kicad_pcb, Hotair-soldering-station.sch, hotair-soldering-station-main-pcb.kicad_pcb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]
2020-11-05 schematc footprint assign, start pcb routing
    [hotair-soldering-station-main-pcb.sch]
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2021-01-03 LED display, buzzer and PWM done in SW. Some HW bugs fixed.
    [Hotair-soldering-station.kicad_pcb, Hotair-soldering-station.sch, hotair-soldering-station-main-pcb.kicad_pcb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]
2021-01-07 Fan DC converter new design, ADC and PWM done
    [hotair-soldering-station-main-pcb.kicad_pcb, hotair-soldering-station-main-pcb.sch]
2021-01-17 Test buzzer, fan, display - done, started temp measuerment
    [Soldering-station Debug.cfg]
2021-06-29 PCB V1.1 - New fan regulator, add MAX31855
    [Hotair-soldering-station.kicad_pcb, Hotair-soldering-station.sch, hotair-soldering-station-main-pcb.kicad_pcb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]
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2021-08-05 HV circuit resistor change, update footprints
    [hotair-soldering-station-main-pcb.kicad_pcb, hotair-soldering-station-main-pcb.sch]
2021-08-06 Main board routing, remove old 7seg from front panel schematic
    [Hotair-soldering-station.sch, hotair-soldering-station-main-pcb.kicad_pcb, hotair-soldering-station-main-pcb.sch]
2021-10-12 uC change to STM32F103
    [Hotair-soldering-station.sch, hotair-soldering-station-main-pcb.kicad_pcb, hotair-soldering-station-main-pcb.sch]
2021-10-15 Display change to LCD
    [Hotair-soldering-station.kicad_pcb, Hotair-soldering-station.sch, hotair-soldering-station-main-pcb.sch]
2021-11-07 Add front panel menu sw, remove lcd, reorganization of uC pinout
    [Hotair-soldering-station.sch, hotair-soldering-station-main-pcb.sch]
2021-11-08 LCD connector main pcb
    [hotair-soldering-station-main-pcb.sch]
2022-01-23 Pin assign to new STM32F103, front panel design to new case
    [Hotair-soldering-station.kicad_pcb, Hotair-soldering-station.kicad_sch, Soldering-station Debug.cfg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]
2022-01-25 Routing PCB, front panel design progress
    [front panel.dxf, hotair-soldering-station-main-pcb (1).kicad_pcb, hotair-soldering-station-main-pcb (1).kicad_sch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]
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2022-02-06 Front panel V2, PCB text alignment, drill resize, T12 connector split
    [front panel V1.dxf, front panel V2a.dxf, front panel.dxf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]
2022-02-07 Fixing DRC violations
    [hotair-soldering-station-main-pcb .kicad_pcb, hotair-soldering-station-main-pcb .kicad_sch, hotair-soldering-station-main-pcb .sch]
2022-02-13 PCB silkscreen progress, remove DRC violations
    [hotair-soldering-station-main-pcb .kicad_pcb]
2022-02-14 Main PCB in production! Generate gerber, add silkscreen logos, expose cu on high current traces, some other minor refinements
    [SHW01-MainPCB-gerber -B_Cu.gbl, SHW01-MainPCB-gerber -B_Mask.gbs, SHW01-MainPCB-gerber -B_Silkscreen.gbo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]
2022-02-19 Front Panel PCB design
    [Hotair-soldering-station.kicad_pcb, Hotair-soldering-station.kicad_sch, Hotair-soldering-station.sch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]
2022-03-06 Configure STM32F1 uC. Fix reset pin and UART problems.
    [Soldering station.cfg, hotair-soldering-station-main-pcb .kicad_pcb, hotair-soldering-station-main-pcb .kicad_sch]
2022-03-10 TIM3 peripheral conflict workaround, add LCD lib
    [Soldering station.ioc, main.c, tim.c]
2022-03-11 Larger IDC conenctor pads for front panel
    [Hotair-soldering-station.kicad_pcb]
2022-03-14 LCD and MAX31855 working, tested buzzer
    [Hotair-soldering-station.kicad_pcb, Hotair-soldering-station.kicad_sch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]
2022-04-13 T12 and WEP tests done
    [Hotair-soldering-station.kicad_pcb, Hotair-soldering-station.kicad_sch, Temperature sensors calibration table.ods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]
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2022-04-20 Ideas and documentation of station, schematic V1.2 update
    [hotair-soldering-station-main-pcb .kicad_sch]
2022-04-23 Last code refinement,, hotair reed switch fix
    [uchwyt hotair.stl, zatrzask hotair.stl]
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2022-04-26 Main and front PCB schematic rearrangement.
    [Hotair-soldering-station.kicad_pcb, Hotair-soldering-station.kicad_sch, hotair-soldering-station-main-pcb .kicad_sch]
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2022-05-04 Schematic V1.2: Drawed concept of new mosfet gate driver, a lot of minor changes
    [hotair-soldering-station-main-pcb .kicad_sch]
2022-05-05 Schematic and PCB update
    [hotair-soldering-station-main-pcb .kicad_pcb, hotair-soldering-station-main-pcb .kicad_sch]
2022-05-06 Alternative thermocouple amplifier for WEP
    [hotair-soldering-station-main-pcb .kicad_sch]
2022-05-10 All knowned problems fixed on schematic, routing mains voltage section
    [hotair-soldering-station-main-pcb .kicad_pcb, hotair-soldering-station-main-pcb .kicad_sch]
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2022-05-16 Routing PCB done, resolving DRC violations
    [hotair-soldering-station-main-pcb .kicad_pcb, hotair-soldering-station-main-pcb .kicad_sch]
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2022-05-17 Front panel rocker switch connector change, preparing pcb for production
    [Hotair-soldering-station.kicad_pcb, hotair-soldering-station-main-pcb .kicad_pcb, hotair-soldering-station-main-pcb .kicad_sch]
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2022-06-02 SMPS case done, add 3D print gcode and stl
    [SMPS case - obudowa główna.stl, SMPS case - pokrywka.stl, SMPS case - stopa.stl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]
2022-06-03 Zener diode footprint and orientation change
    [hotair-soldering-station-main-pcb .kicad_pcb, hotair-soldering-station-main-pcb .kicad_sch]
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

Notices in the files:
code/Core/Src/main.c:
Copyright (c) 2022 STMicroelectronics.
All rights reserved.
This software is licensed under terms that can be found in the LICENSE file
